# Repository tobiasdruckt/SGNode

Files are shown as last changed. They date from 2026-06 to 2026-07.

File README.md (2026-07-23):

# SGNode Intelligent Fermentation Assistant

**Release:** alpha 0.5.0  
**Platform:** ESP32 float + standalone ESP32 base station with 4-inch touchscreen

SGNode is a self-contained fermentation monitor and assistant. A battery-powered float measures tilt, temperature, and battery voltage. The base station receives data over ESP-NOW, stores batches on SD card, and provides all setup, charts, recommendations, and management directly on the built-in touchscreen.

No web UI, phone app, REST frontend, or external dashboard is used.

## Current Status

SGNode remains in **alpha** while SGNode Plug temperature control is still awaiting real water/fridge validation. Float/Base have completed real-batch use, but the Plug controller should pass water tests before the project moves to beta.

## Current Capabilities

### Base Station
- Native touchscreen UI with Live, Graph, Dashboard, Details, Battery, and More views
- Brew Wizard for batch name, style, volume, Brix, yeast, attenuation, and diacetyl rest
- Auto Mode with yeast behavior presets and custom yeast templates
- Brix to SG conversion, expected FG, attenuation, ABV, gravity slope, and ETA
- OG verification using first stable measured SG, with recipe/measured choice
- Batch-start float zero calibration with explicit "put float in brew" confirmation before logging
- Target gravity, temperature, angle, and ABV charts
- Fermentation state machine and on-device recommendations
- Batch management: continue, copy, and delete stored batches
- Yeast management: create, edit, delete, and select custom yeast presets
- Local persistence on SD card under `/data/batches/<batch_id>/`
- Debug levels for quieter serial output
- Light/dark theme with persistent setting
- Integration of SGNode Plug temperature control for precise fermentation temperatures
- Enhanced batch management: versioning and rollback options for stored batches
- Improved yeast management: compatibility with more yeast types and strain-specific parameters
- Real-time alerts for critical conditions such as excessive tilt or low battery voltage
- User feedback system for providing immediate suggestions based on sensor data and recipe adjustments

### Float Unit
- BMI160 tilt measurement and BMI160 chip-temperature diagnostics
- Polynomial gravity calibration stored in EEPROM
- ESP-NOW packet transmission with protocol version and CRC
- Battery voltage reporting
- Deep sleep between measurement cycles
- Calibration mode via hardware switch and base station workflow

## Hardware

### Float
- WeMos D32 ESP32 board with 18650 holder
- BMI160 IMU on I2C
- BMP180/GY-68 removed in the current low-power build
- 18650 Li-ion cell
- Calibration switch on GPIO12
- Waterproof enclosure

### Base
- 4.0-inch ESP32-32E touchscreen display module
- MicroSD card, FAT32
- 5V USB power supply
- Optional DS323x-compatible RTC on SDA GPIO32 and SCL GPIO25

See [hardware.md](hardware.md) and [WIRING_DIAGRAM.md](WIRING_DIAGRAM.md) for pin details.

## Firmware Layout

```text
SGNode_Base/
  SGNode_Base.ino                 Base station firmware and UI orchestration
  src/
    assets/                       Boot logo data
    calculations/                 Brix, gravity, ETA, OG, and target curve logic
    domain/                       Batch model, yeast presets, state, and recommendations
    test/                         Optional serial UI test harness
    ui/                           Brew Wizard and shared touchscreen UI helpers

SGNode_Float/
  SGNode_Float.ino                Float firmware
  polynomial_calibration.h         Float calibration logic

SGNode_Plug/
  SGNode_Plug.ino                 ESP8285 smart-plug temperature controller
  src/                            Plug sensors, ESP-NOW transport, PI control, and relay logic

SGNode_Shared/
  sg_protocol.h                   ESP-NOW payload format
  plug_hardware.h                 Plug pin assignment
```

## SD Card Structure

```text
/data/
  batches/
    batch_001/
      profile.json
      target.json
      log.csv
  yeast/
    <custom_yeast>.json
  yeasts.txt
  yeast_history.json
```

`log.csv` contains timestamp, epoch, uptime, angle, density, diagnostic float temperature, battery, fermentation state, attenuation, ABV, recommendation code, and optional Plug temperature-control fields. Historical data is loaded after reboot and should be visible immediately.

## Setup

1. Install Arduino IDE 2.x and ESP32 board support.
2. Install libraries:
   - TFT_eSPI
   - XPT2046_Touchscreen
   - EmotiBit BMI160
   - SD, FS, SPI, Wire, EEPROM
3. Configure TFT_eSPI for the 4.0-inch ESP32-32E display.
4. Flash `SGNode_Base/SGNode_Base.ino`.
5. Temporarily set `SGNODE_DEBUG_LEVEL` to `DEBUG_INFO` and read the base station MAC address from Serial Monitor.
6. Set that MAC in `SGNode_Float/SGNode_Float.ino`.
7. Flash the float.
8. Insert a FAT32 MicroSD card into the base station.
9. Use the touchscreen Brew Wizard to create the first batch.

Optional SGNode Plug build:

- Install ESP8266 board support.
- Install `OneWire` and `DallasTemperature`.
- Compile `SGNode_Plug/SGNode_Plug.ino` as `Generic ESP8266 Module`, 1 MB flash, DOUT flash mode, and 80 MHz CPU.
- Include the project root as a local library path so `SGNode_Shared` headers are visible.

## Normal Operation

1. Create or continue a batch on the base station.
2. Follow the Dashboard action `Level Float` if a batch-start zero calibration is required.
3. Place the float in the fermenter only after zero calibration is complete.
4. Confirm `Put Float In Brew` on the Dashboard.
5. The float wakes, measures, transmits, and returns to sleep.
6. The base station updates the Live screen, charts, dashboard, recommendations, ETA, and CSV log.
7. Use More > Manage Brew to continue, copy, or delete batches.
8. Use More > Manage Yeast to maintain custom yeast presets.

## Batch Start Workflow

SGNode intentionally separates preparation from the real batch start.

1. Brew Wizard creates the batch profile and target curve.
2. Dashboard shows `Level Float`.
3. Put the float on a level reference surface and press `READY`.
4. Base waits for the next normal float packet and sends a zero-calibration command in the ESP-NOW ACK.
5. Float performs a short accelerometer zero calibration, stores the offset, and reports success in a later packet.
6. Dashboard then shows `Put Float In Brew`.
7. Place the float in the wort/beer and press `DONE`.

Before `Put Float In Brew` is confirmed, incoming float packets are allowed to update the live display but are not written to the active batch CSV and are not used for OG detection or fermentation state changes. This prevents handling, air, and table measurements from contaminating the batch history.

When `Put Float In Brew` is confirmed:

- `createdAt` is reset to the confirmation time.
- the RAM write buffer is cleared.
- the active `log.csv` is recreated with only the header.
- the target curve is regenerated from the real batch start.
- OG stability detection and normal SD logging begin.

## Calibration

Calibration is started from the base station and executed by the float.

1. Turn on the float calibration switch.
2. Open More > Calibration on the base station.
3. Record the offset on a level surface.
4. Record SG points in known solutions.
5. Apply calibration to save polynomial coefficients to float EEPROM.
6. Turn off the calibration switch to return to deep sleep operation.

Current calibration uses the existing float firmware. Adding new optional calibration points normally requires float firmware changes because the float owns the polynomial calculation and EEPROM format.

### Batch-Start Zero Calibration

The batch-start zero calibration is separate from polynomial SG calibration. It only updates the accelerometer zero offset used for tilt.

- It runs in normal float operation, not in the long calibration mode.
- The float remains on a level reference surface.
- Base sends the zero-calibration command inside the normal ACK/downlink packet.
- Float uses a short sample window, saves the offset if the raw acceleration is plausible and stable, and then returns to sleep.
- If zero calibration fails, keep the float level and repeat the Dashboard action.

## Debug Output

Base station serial logging is controlled in `SGNode_Base.ino`:

```cpp
#define SGNODE_DEBUG_LEVEL DEBUG_ERROR
```

Levels:
- `DEBUG_QUIET`
- `DEBUG_ERROR`
- `DEBUG_INFO`
- `DEBUG_VERBOSE`

Use `DEBUG_INFO` temporarily for setup details such as the base station MAC address. Use `DEBUG_VERBOSE` only when diagnosing packet, SD, graph, or calibration behavior.

## Troubleshooting

### Historical graphs are empty after reboot
- Check Details > System:
  - `SD OK` means the active log path is usable.
  - `CSV L/T` means loaded rows / total rows.
  - `Buf` means unsaved RAM buffer entries.
- If `T` is correct but `L` is low, rows may be outside the selected time range or older than the active batch start timestamp.
- If `Buf` is high before reboot, those rows have not been flushed to SD yet.

### Old data appears in a new batch
- Confirm the active batch in Manage Brew.
- Current builds avoid reusing existing batch directories and filter rows older than the active batch creation time.
- For a new batch, confirm `Put Float In Brew` before expecting CSV rows. Data received before that confirmation is intentionally not logged.

### New batch receives float packets but log stays empty
- This is expected until `Put Float In Brew` has been confirmed.
- The Live screen can show current float data before the batch is armed.
- Confirm the Dashboard action after the float is actually in the wort/beer.

### No float data received
- Verify the base station MAC in the float sketch.
- Confirm both devices are powered.
- Check ESP-NOW channel and antenna placement.
- Use `DEBUG_INFO` or `DEBUG_VERBOSE` temporarily.

### SD card issues
- Use FAT32.
- Try a different MicroSD card.
- Insert the card before boot.
- Check that `/data/batches/<batch_id>/log.csv` exists.

### Battery drains too fast
- Verify the float is entering deep sleep.
- Keep calibration mode off during normal use.
- Confirm measurement delay/sleep interval settings.
- Current reference hardware reached about `0.95 mA` deep sleep after removing the BMP180/GY-68 and isolating the USB-UART chip.
- The ME6220 regulator swap did not provide enough improvement to justify the rework by itself.
- Check IMU suspend state and USB-UART leakage first if hardware current remains high.

## Release Notes

See [RELEASE_NOTES_v0.5.0-alpha.md](RELEASE_NOTES_v0.5.0-alpha.md).

## Status

alpha 0.5.0 is ready for hands-on testing. Float/Base have completed a first real batch, while SGNode Plug remains alpha until water/fridge validation is complete.

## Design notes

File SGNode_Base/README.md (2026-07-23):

# SGNode Base Firmware

## OTA Update

Base OTA is a manual maintenance mode.

1. Open the bottom `More` tab.
2. Tap `OTA Update`.
3. Confirm `Start Base OTA?`.
4. Connect to the SoftAP shown on the display, for example `SGNode-Base-OTA-xxxxxx`.
5. Open `http://192.168.4.1/` and upload the new `.bin`.

During OTA the base pauses normal ESP-NOW operation. The OTA mode stays active while a client is connected. If no client connects for 180 seconds, the base reboots back into normal operation.

The OTA page also provides compact diagnostics at `/diag` and a `Reboot normal mode` link.

## Display Brightness

The `More` tab has a `Brightness` item. It cycles through `Low`, `Mid`, `High`, and `Max` using PWM on GPIO27, which is the LCD backlight pin on the ESP32 display board.

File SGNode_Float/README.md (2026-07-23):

# SGNode Float Firmware

**Release:** alpha 0.5.0  
**Role:** Battery-powered ESP32 sensor float

The float measures tilt, diagnostic BMI160 chip temperature, and battery voltage, converts tilt to specific gravity using stored calibration coefficients, and sends packets to the base station via ESP-NOW.

## Hardware

- WeMos D32 ESP32 board with 18650 holder
- BMI160 IMU on I2C, GPIO26 SDA and GPIO27 SCL
- BMP180/GY-68 removed in the current low-power hardware revision
- Battery voltage divider on GPIO15
- Calibration switch on GPIO12
- Status LEDs on GPIO5 and GPIO16

## Main Behavior

1. Wake from sleep.
2. Read battery before Wi-Fi activity.
3. Initialize sensors.
4. Collect filtered tilt and temperature readings.
5. Calculate specific gravity.
6. Send ESP-NOW payload with protocol version and CRC.
7. Return to deep sleep.

Calibration switch ON keeps the float awake for the base station calibration workflow.

## OTA Update

Float OTA is a manual service mode.

1. Wake or power the float while holding the calibration switch.
2. Keep the switch held for 5 seconds.
3. The float sends an `OTA Active` packet to the base station, then starts a SoftAP such as `SGNode-Float-OTA-xxxxxx`.
4. Connect to the SoftAP and open `http://192.168.4.1/`.
5. Upload the new `.bin`.

During OTA the float does not enter deep sleep. The mode has a hard 20 minute timeout to protect the battery. Holding the calibration switch for 5 seconds while OTA is active reboots back to normal mode. The web page also has a `Reboot normal mode` link and compact diagnostics at `/diag`.

## Required Libraries

- EmotiBit BMI160
- Wire
- EEPROM

## Configuration

Set the base station MAC address in `SGNode_Float.ino`:

```cpp
uint8_t baseStationMac[] = {0xA4, 0xF0, 0x0F, 0x68, 0x22, 0x00};
```

The shared payload format is defined in `../SGNode_Shared/sg_protocol.h`.

## Calibration

Calibration coefficients are stored in EEPROM. The base station sends calibration commands while the float is in calibration mode.

Current behavior:
- Sensor offset calibration is supported.
- Multiple SG points are recorded.
- Polynomial coefficients are calculated on the float.
- EEPROM versioning is used for backward compatibility.

Adding extra optional calibration points normally requires flashing the float because the point handling, polynomial fit, and EEPROM format live in the float firmware.

## Power Notes

- Deep sleep is the expected normal state.
- Calibration mode has high drain because the float stays awake.
- Battery measurement uses GPIO15 with a calibrated voltage divider.
- If battery drain is high, first confirm that the float is not staying in calibration mode and that the sleep interval is actually reached after each send.

## Troubleshooting

- No packets: check base station MAC and ESP-NOW channel.
- Wrong SG: recalibrate and verify the float is mechanically stable.
- Unexpected temperature: remember this is BMI160 chip temperature for diagnostics, not beer temperature.
- Battery reads wrong: verify the divider and calibration factor.
- Fast drain: inspect deep sleep entry and sensor power behavior.

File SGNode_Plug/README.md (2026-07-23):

# SGNode Plug firmware

Target hardware: Gosund SP1 with ESP8285 and removed power-measurement circuit.

## Pin assignment

| GPIO | Function |
| --- | --- |
| 1 | Secondary LED |
| 3 | Button |
| 4 | Fridge-air DS18B20 data |
| 5 | Beer/vessel DS18B20 data |
| 13 | Primary LED |
| 14 | Relay, active high |

Each DS18B20 uses a separate OneWire bus and needs a 4.7 kOhm pull-up from
its data line to 3.3 V.

The relay is initialized OFF before any controller logic runs.

## Control behavior

- The Base sends beer target, ramp rate, and batch size by ESP-NOW.
- The Plug keeps a rolling beer-probe history and updates its outer controller
  once per minute.
- The outer PI/D-brake controller derives an air target. The inner controller
  switches the relay around that target with asymmetric thresholds above the
  air target. Current defaults switch off at air target + 0.5 K and on at air
  target + 1.1 K to compensate for fridge aftercool.
- If the beer probe fails while the air probe remains valid, the last air
  target is held.
- If the air probe fails, a complete learned six-hour compressor pattern is
  replayed. Without a complete pattern, the relay remains off.
- Every Plug status contains both temperatures, targets, controller state,
  faults, relay state, and the rolling ten-minute duty cycle.

Controller parameters are sent by Base with each command. Base stores the
editable defaults on the SD card in `/data/plug/gov_settings.json`.

The Base learns the MAC of the first valid Plug status packet and stores it in
EEPROM. Plug control remains disabled by default and can be enabled per batch
with the Brew Wizard `SGNode Plug` step.

## OTA update mode

Hold the Plug button for 5 seconds to enter OTA update mode. The relay is
switched off immediately and stays off. Normal ESP-NOW control is paused, and
the Plug starts an open SoftAP named `SGNode-Plug-OTA-<ChipId>`.

Connect to the AP and open:

- `http://192.168.4.1/`
- `http://192.168.4.1/update`
- `http://192.168.4.1/diag`

The root/update page contains a minimal firmware upload form, a normal-mode
reboot button, and compact diagnostics. After a successful upload the Plug
reboots. OTA mode remains active while a client is connected to the SoftAP. If
no upload is in progress and no client is connected for 180 seconds, OTA mode
times out and reboots so ESP-NOW starts cleanly again. Holding the hardware
button for 5 seconds while already in OTA mode also reboots to normal mode.

During OTA both LEDs blink. The secondary LED is on GPIO1/UART TX and may also
flicker when serial output is active.

## Build target

Use `Generic ESP8266 Module`, 1 MB flash, DOUT flash mode, and 80 MHz CPU.

Required libraries:

- OneWire
- DallasTemperature

The shared headers in `SGNode_Shared` are used as a local project library when
compiling the Plug.

## Bench-test order

The low-level bench-test sketches are intentionally local-only and ignored by
Git. Keep them beside the repo when working on hardware, but do not publish
them as part of the main firmware tree.

1. Flash local `SGNode_Plug_Hardware_Check` and verify the serial pin report.
2. With no 230 V connection, flash local `SGNode_Plug_Sensor_Relay_Test`.
3. Verify both temperatures on serial and relay continuity with a multimeter.
4. Flash `SGNode_Plug` only after the sensor assignment and relay polarity are
   confirmed.

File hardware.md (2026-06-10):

# SGNode Hardware Notes

**Current release:** alpha 0.5.0

## Bill Of Materials

### Float Unit

| Part | Qty | Notes |
| --- | ---: | --- |
| WeMos D32 ESP32 board | 1 | Built-in 18650 holder and charger |
| BMI160 IMU | 1 | Tilt measurement |
| BMP180 / GY-68 | 0 | Removed from current float build; BMI160 chip temperature is used for diagnostics |
| 18650 Li-ion cell | 1 | 2000 mAh or larger recommended |
| SPST switch | 1 | Calibration mode on GPIO12 |
| Waterproof enclosure | 1 | Must fit fermenter opening |

### Base Station

| Part | Qty | Notes |
| --- | ---: | --- |
| 4.0-inch ESP32-32E display module | 1 | Integrated ESP32, ST7796 display, touch |
| MicroSD card | 1 | FAT32, 4 GB or larger |
| 5V USB power supply | 1 | 2 A recommended |
| DS323x-compatible RTC | 1 | Optional but recommended for stable timestamps |

## Float Pin Summary

| Signal | GPIO | Notes |
| --- | ---: | --- |
| I2C SDA | 26 | BMI160 |
| I2C SCL | 27 | BMI160 |
| Battery ADC | 15 | 51k/51k divider plus capacitor |
| Calibration switch | 12 | Switch to GND |
| Built-in LED | 5 | Status |
| Extra LED | 16 | Calibration indicator |

## Float Hardware Revision Notes

- The BMP180/GY-68 has been removed from the float. It self-heated the small float interior and did not provide a reliable beer-temperature measurement.
- Current firmware reports BMI160 chip temperature. Treat this as a diagnostic value, not as representative wort/beer temperature.
- The current Float firmware no longer requires any BMP/BMP180 support library.
- The USB-UART chip was isolated by cutting pin 8 on the CP2302/USB-UART package used on the tested board. This reduced sleep leakage on the reference float.
- The voltage regulator was replaced with an ME6220 during testing. The improvement was small and is not considered worth the rework by itself.
- Current measured reference sleep current after the practical hardware changes is about `0.95 mA`.

## Base Pin Summary

The 4-inch base module has display, touch, and SD wiring integrated. Current firmware also supports an RTC:

| Signal | GPIO |
| --- | ---: |
| RTC SDA | 32 |
| RTC SCL | 25 |
| SD CS | 13 |
| Display CS | 5 |
| Touch CS | 15 |

## Assembly Notes

- Keep the float antenna area clear of metal.
- Mount the IMU rigidly; movement inside the enclosure will ruin calibration.
- Put the battery low in the float for stable orientation.
- Seal the float enclosure before real fermentation use.
- Keep SD card access available on the base enclosure.
- Use a stable 5V supply for the base station; display and SD writes need margin.

## Power Notes

### Float

- Normal operation should spend most time in deep sleep.
- Calibration mode keeps the float awake and drains the battery quickly.
- If drain is high, measure sleep current directly and confirm BMI160 suspend behavior and USB-UART leakage.
- Do not use the removed BMP180 as a beer-temperature reference in new builds.

### Base

- Designed for powered operation, not battery operation.
- Typical draw depends heavily on display backlight.
- SD access is mounted only when needed to reduce SPI/touch conflicts.

## Enclosure Targets

### Float

- PETG or ABS preferred.
- Waterproof target: IP67 style sealing.
- Stable buoyancy and consistent tilt response are more important than minimum size.

### Base

- Desktop stand or wall mount.
- Access for USB and MicroSD.
- Passive ventilation for ESP32 and display driver.

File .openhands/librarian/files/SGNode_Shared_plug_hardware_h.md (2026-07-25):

# SGNode_Shared/plug_hardware.h

**Type:** C++ Header
**Hash:** `9040c98aef18a2a87f8e2de6f7bfb239a11960e1cd32cc37a2c1f87b4a31860b`

## Overview / Role

Hardware pin definitions and inline functions

## Verified API & Symbols

### Functions

- `void beginRelayOff (void)`

- `void setRelay (bool on)`

## Key Dependencies

**System/External:**
- `<Arduino.h>`

## Side Effects & Hardware Access

- Relay control (fridge compressor)
- I2C bus communication
- OneWire bus communication
- Serial port initialization

## Change Risks

- **MEDIUM**: Core functionality change

---
*Last modified (hash): 9040c98aef18a2a87f8e2de6f7bfb239a11960e1cd32cc37a2c1f87b4a31860b*

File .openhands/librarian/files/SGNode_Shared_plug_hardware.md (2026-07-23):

# SGNode_Shared/plug_hardware.h

**Type:** C++ Header
**Hash:** `9040c98aef18a2a87f8e2de6f7bfb239a11960e1cd32cc37a2c1f87b4a31860b`

## Role

Hardware pin definitions and low-level control helpers.

## Verified API / Symbols

- Functions: beginRelayOff, setRelay

## Key Dependencies

- Arduino.h

## Side Effects

- Relay control (fridge compressor)
- I2C/SPI bus communication

## Tests

- No dedicated automated test identified

## Change Risks

- **MEDIUM**: Core functionality change

---
*Last modified (hash): 9040c98aef18a2a87f8e2de6f7bfb239a11960e1cd32cc37a2c1f87b4a31860b*

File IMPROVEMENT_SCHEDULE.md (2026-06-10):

# SGNode Improvement Backlog

**Updated:** 2026-06-10

**Current release:** alpha 0.5.0

This backlog tracks the active alpha work. Historical release contents live in the release notes; this file should stay focused on the next useful checks and implementation steps.

## Current Alpha Status

- Float/Base completed a first real fermentation run.
- SGNode Plug firmware and Base integration exist, but Plug control has not yet passed the water/fridge validation run.
- New batches are gated by quick zero calibration and a required `Put Float In Brew` confirmation before CSV logging starts.
- The current Float reference build removed the BMP180/GY-68. BMI160 chip temperature is kept as a diagnostic value only.
- Reference Float deep sleep current is about `0.95 mA` after practical low-power changes.
- Low-level Plug test sketches are kept local-only and ignored by Git.

## Completed Since v0.4.0

- Batch-start quick zero calibration via Float ACK command.
- Required `Put Float In Brew` action to separate setup packets from real batch logging.
- Manage Brew delete geometry and old-batch directory deletion fixes.
- SGNode Plug alpha firmware for Gosund SP1 / ESP8285.
- Base/Plug ESP-NOW command and status protocol.
- Base-side Plug MAC learning, persisted status, command sender, UI diagnostics, and CSV fields.
- Brew Wizard `SGNode Plug` step for per-batch Plug Auto Mode.
- Hardware documentation update for BMP removal, CP2302 pin isolation, and realistic regulator-swap benefit.

## Active Alpha Priorities

### 1. SGNode Plug Water/Fridge Validation

- Run the Plug with water, both DS18B20 sensors, and the fridge before using Plug Auto Mode on beer.
- Confirm relay polarity, command acknowledgement, stale-status handling, and compressor duty logging.
- Validate PI outer-loop behavior for realistic batch volumes and temperature ramps.
- Check cold-crash behavior with the 1.0 C absolute air-target clamp, static 3 K clamp, and dynamic 5 K clamp.
- Tune default `Tn` values after measured water-test response data exists.

### 2. Batch Start And Logging Validation

- Re-test the full new-batch flow on hardware: wizard, quick zero, `Put Float In Brew`, first logged CSV row.
- Confirm packets received before `Put Float In Brew` update the live display but do not enter the batch CSV.
- Confirm completed batches remain read-only enough for normal UI use.
- Keep active-batch restore behavior covered when older and newer batch directories coexist.

### 3. Fermentation Logic Validation

- Compare dry-hop, cold-hop, cold-crash, and package recommendations against real fermentation data.
- Validate action hysteresis so repeated recommendations do not appear and disappear around SG thresholds.
- Continue tuning ETA from smoothed recent SG slope and phase state.
- Store enough yeast performance summary data for future learning, but defer broad learning features until basic thresholds are stable.

### 4. Float Hardware And Power Validation

- Repeat sleep-current measurement after the BMP removal and calibration ACK changes.
- Confirm the BMI160-only build wakes, sends, receives calibration commands, and returns to deep sleep reliably.
- Document any remaining board-specific leakage paths only after measurement.
- Do not reintroduce BMP/BMP180 libraries or wiring for the current reference Float.

### 5. Documentation And Release Hygiene

- Keep README, hardware notes, wiring diagram, release notes, and Plug plan aligned before each GitHub push.
- Keep historical release notes historical; new behavior belongs in the current release notes.
- Keep local-only hardware test sketches out of Git while documenting their purpose.
- Revisit beta status only after Plug water/fridge validation is complete.

## Beta Gate

SGNode should stay alpha until these points are true:

- Plug water/fridge test passes without unsafe relay behavior.
- Plug and Base logs show coherent Float plus Plug rows over a realistic run.
- Batch-start gating is stable on real hardware.
- No critical SD/history loss is observed during normal reboot and batch-management flows.
- The documentation describes the actual hardware and required libraries without stale BMP or test-sketch assumptions.

## Later Ideas

- Sugar/priming calculator based on batch volume, target CO2, beer temperature, and bottle size.
- Centralized error code model.
- More robust settings screen.
- Export helpers for SD card data.
- Automated simulator tests for calculations and state machine.
- Optional additional calibration points if real Float data proves they are needed.

## Rule For Alpha

Prefer small, testable fixes over broad refactors. Every change should preserve existing manual mode, Auto Mode, SD history, batch-start gating, and calibration behavior.

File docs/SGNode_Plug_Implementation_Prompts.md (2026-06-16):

# SGNode Plug Implementation Prompts

Working notes for adding an ESP8285-based smart plug as a standalone fridge controller for SGNode.

These notes are intentionally split into small implementation prompts. Each prompt should be usable as a focused task later.

## Current Implementation Status

SGNode Plug is implemented and has passed initial bench plus first 13 L water/fridge validation, including clean 9 C and 4 C holds. It remains **alpha** until other fill levels and at least one real fermentation validate the controller.

| Stage | Status | Notes |
| --- | --- | --- |
| 1. Hardware validation | Done for current bench hardware | Gosund SP1, ESP8285, power metering removed, GPIO4/GPIO5 freed, relay active-high on GPIO14 |
| 2. Dual DS18B20 serial test | Done for current hardware | `SGNode_Plug_Sensor_Relay_Test` is kept local-only and ignored by Git; sensor assignment was validated before Plug firmware testing |
| 3. Plug firmware skeleton | Implemented | `SGNode_Plug/SGNode_Plug.ino` and supporting modules exist |
| 4. Local air controller | Implemented | Asymmetric air thresholds implemented; current defaults are off at air target + 0.5 K and on at air target + 1.1 K |
| 5. Rolling statistics and fallback | Implemented | 10-minute duty and six-hour pattern fallback implemented; replay behavior needs live validation |
| 6. ESP-NOW protocol | Implemented | Shared command/status structs, Base MAC learning, persisted Plug MAC, and status handling are present |
| 7. Outer PI beer controller | Implemented | Explicit Base-sent `Kp`, `Tn`, D-brake, clamps, and air-target derivation are implemented |
| 8. Base batch/UI integration | Implemented | Brew Wizard Plug toggle, Base command sender, status display, and Plug temperature preference are present |
| 9. Shared CSV integration | Implemented | Batch CSV includes Plug status fields while remaining backward-compatible |
| 10. Water tests and tuning | In progress | First 13 L test produced usable defaults; other fill levels and real fermentation validation remain before beta |

Open validation before beta:

- Validate both DS18B20 probes over longer operation on real wiring.
- Run low-voltage relay/contact test without 230 V load.
- Run water/fridge test with several fill levels.
- Validate PI `Kp`, batch-size-to-`Tn`, 3 K hold clamp, 5 K transition clamp, 1.0 C minimum air target, compressor timing, and fallback behavior.
- Confirm Base logs coherent Float + Plug rows during the test.
- Confirm cold-crash transition behavior with water before using Plug auto mode on a live batch.

## Implementation Order

Implement and validate SGNode Plug in the following order. Do not proceed to the next stage until the current stage has passed its checks.

### Stage 1: Hardware Validation

- Confirm GPIO4 and GPIO5 are electrically isolated after removing the power-metering hardware.
- Confirm GPIO14 relay is active-high.
- Confirm relay remains off during boot/reset/flash.
- Document final wiring and sensor cable routing.

Exit criteria:

- GPIO4/GPIO5 can be safely driven/read at 3.3 V.
- Relay behavior is known and repeatable.
- No mains-connected testing is required for unresolved low-voltage wiring.

### Stage 2: Dual DS18B20 Serial Test Sketch

- Create or keep a standalone local hardware-test sketch before implementing SGNode Plug firmware.
- Suggested local path: `SGNode_Plug_Sensor_Relay_Test/SGNode_Plug_Sensor_Relay_Test.ino`.
- Connect fridge-air DS18B20 to GPIO4.
- Connect vessel/beer DS18B20 to GPIO5.
- Use one 4.7 kOhm pull-up to 3.3 V on each data line.
- Read both sensors independently and print both temperatures over Serial.
- Print explicit errors for missing, disconnected, invalid, or CRC-failing sensors.
- Force GPIO14 low immediately at startup.
- After both sensors provide valid values, control the relay using a simple differential test rule:
  - If vessel/beer sensor is warmer than fridge-air sensor, switch cooling relay on.
  - If fridge-air sensor is warmer than vessel/beer sensor, switch cooling relay off.
- Add a small differential hysteresis to prevent relay chatter when both values are nearly equal.
- If either sensor is invalid, keep the relay off.
- Run this hardware test without 230 V AC connected.
- Verify relay contact continuity only with a multimeter.
- Do not connect a refrigerator or other mains load during this test.

Suggested Serial output:

```text
AIR 20.31 C | BEER 20.44 C | AIR_OK=1 | BEER_OK=1 | RELAY=ON | STATE=BEER_WARMER
```

Exit criteria:

- Both sensors are detected consistently across multiple resets.
- Both temperatures update independently.
- Disconnecting either sensor reports the correct individual fault.
- Relay switches on when the beer sensor is sufficiently warmer than the air sensor.
- Relay switches off when the air sensor is sufficiently warmer than the beer sensor.
- Relay does not chatter when both values are nearly equal.
- Invalid sensor data always switches or keeps the relay off.
- Multimeter continuity confirms the expected relay contact state.

### Stage 3: Plug Firmware Skeleton

- Create `SGNode_Plug/SGNode_Plug.ino`.
- Initialize relay safe-off, both sensors, timing, diagnostics, and fixed Base peer MAC.
- Implement controller state machine without switching a real compressor yet.
- Print calculated states and relay requests over Serial.

Exit criteria:

- Firmware boots reliably.
- Sensor readings and controller states are stable.
- No unexpected relay activation occurs.

### Stage 4: Local Air Two-Point Controller

- Implement the inner fridge-air controller.
- Add asymmetric thresholds relative to air target.
- Current defaults: relay off at air target + 0.5 K, relay on at air target + 1.1 K.
- Add minimum compressor off/on timing.
- Test first with a lamp or other non-compressor load if practical.

Exit criteria:

- Relay follows air target and hysteresis correctly.
- Minimum compressor timing cannot be bypassed.
- Relay remains off during invalid startup state.

### Stage 5: Rolling Statistics And Time-Pattern Fallback

- Add 10-minute temperature statistics and compressor duty.
- Add rolling six-hour relay-pattern recording.
- Add pattern replay on temperature-measurement failure.
- Keep relay off and report fault if no complete valid pattern exists.

Exit criteria:

- Statistics match measured intervals.
- Invalid sensor periods are not learned.
- Replay preserves the recorded duty pattern while respecting compressor timing.

### Stage 6: ESP-NOW Plug Protocol

- Add Plug command/status packet types to `SGNode_Shared`.
- Plug uses fixed Base MAC.
- Base learns first valid Plug MAC and stores it in EEPROM.
- Implement command acknowledgement, packet validation, status reporting, and `Forget SGNode Plug`.

Exit criteria:

- Plug and Base exchange validated packets reliably.
- Base restart restores learned Plug MAC.
- Foreign Plug packets are ignored after learning.

### Stage 7: Outer PI Beer-Temperature Controller

- Implement requested beer target, internal target ramp, PI controller, and anti-windup on Plug.
- Add batch-size-based `Tn`.
- Add 3 K holding clamp, dynamic 5 K transition clamp, and fast-ramp behavior.
- Report PI state and derived air target to Base.

Exit criteria:

- Controller behaves correctly in simulation/Serial diagnostics.
- Mode transitions are bumpless.
- Output clamps and 1.0 C minimum air target work as specified.

### Stage 8: Base Batch And UI Integration

- Add Plug Auto Mode selection and ramp settings to Batch Wizard.
- Add Plug status, temperatures, controller state, and faults to Base UI.
- Add automatic cold-crash start policy.
- Keep Dry Hop and Package manual.

Exit criteria:

- Existing batches load safely.
- Plug-disabled operation remains unchanged.
- Plug-enabled batch sends correct beer targets and ramps.

### Stage 9: Shared CSV Integration

- Extend the existing batch CSV with Plug values and 10-minute compressor duty.
- Keep parser backward-compatible.
- Use latest known Plug status for Float-triggered rows.

Exit criteria:

- Old CSV files still load.
- New rows contain coherent Float and Plug values.
- No separate Plug log is created.

### Stage 10: Water Tests And Tuning

- Run controlled water tests at multiple fill levels.
- Validate `Kp`, batch-size-to-`Tn` scaling, delays, clamps, and ramp behavior.
- Tune parameters before using automatic control on an active fermentation.

Exit criteria:

- Stable holding performance.
- Controlled ramp performance without excessive overshoot.
- Cold-crash behavior respects configured ramp and temperature limits.

## Current Preferred Concept

Build an SGNode Plug firmware for an ESP8285 smart plug with two added temperature sensors.

Architecture:

- SGNode Base owns fermentation logic, batch state, and the requested beer-temperature profile.
- SGNode Plug owns both temperature measurements and the complete temperature-control loop.
- Base sends only the requested beer temperature, control mode, and profile-transition information via ESP-NOW.
- Plug derives its own fridge-air target from measured beer temperature and controls the fridge relay locally.
- Plug reports both temperatures, derived air target, controller state, and relay state back to Base.
- Base and Plug communication continues independently from Float packets.
- Float packets remain the primary trigger for combined batch CSV rows, but not for temperature-control availability.

Initial control strategy:

- Plug measures fridge air temperature with one DS18B20.
- Plug measures vessel/beer temperature through an immersion sleeve with a second DS18B20.
- When Plug Auto Mode is selected, Plug uses the immersion-sleeve temperature as its controlled process value.
- Float temperature remains available for diagnostics and logging, but is ignored by temperature control while Plug Auto Mode is active.
- Base sends the requested beer-temperature target from the active batch profile.
- Plug runs a slow outer beer-temperature controller that derives a fridge-air target.
- Plug runs an inner two-point fridge-air controller around that derived air target.
- Inner-loop thresholds: cooling on at air target + `Air on`, cooling off at air target + `Air off`.
- Current defaults are `Air off = 0.5 K` and `Air on = 1.1 K` to account for fridge aftercool.
- Plug sends average actual air temperature to Base every 10 minutes.
- Plug adapts its air-temperature target slowly based on the difference between immersion-probe temperature and requested beer target.
- Adaptive correction must be conservative, bounded, autonomous, and visible on Base through status reporting.

Action policy:

- Dry hop requires manual acknowledgement because SGNode cannot know whether hops were physically added.
- Remove dry hop requires manual acknowledgement or skip because SGNode cannot know whether hops were physically removed.
- Cold crash may auto-start when plug auto mode is enabled, the plug is reachable, all previous manual actions are resolved, and SGNode successfully commands the cold-crash target.
- Packaging remains manual.

## Prompt 1: Hardware Discovery

Inspect the ESP8285 smart plug hardware and document the pinout.

Known hardware:

- Smart plug: Gosund SP1
- MCU: ESP8285
- Jumper wires have already been soldered and routed outside the enclosure.

Confirmed external wiring:

| Wire color | Signal |
| --- | --- |
| Purple | RST |
| Blue | GPIO0 |
| Red | 3.3 V |
| Black | GND |
| White | ESP RX |
| Brown | ESP TX |
| Green | GPIO4, freed by removing the power-metering hardware |
| Yellow | GPIO5, freed by removing the power-metering hardware |

Planned sensor assignment:

| GPIO | Sensor role |
| --- | --- |
| GPIO4 | DS18B20 fridge-air sensor |
| GPIO5 | DS18B20 vessel/beer immersion-sleeve sensor |

GPIO4 and GPIO5 are intended as separate OneWire buses. Each bus receives its own pull-up resistor to 3.3 V.

Confirmed hardware modification:

- The power-metering hardware connected to GPIO4/GPIO5/GPIO12 has been desoldered.
- GPIO4 and GPIO5 are therefore available for the two DS18B20 buses.
- Plug power-consumption measurement is intentionally no longer available.
- Before connecting sensors, verify that GPIO4 and GPIO5 are electrically isolated from the removed metering circuit and switch cleanly between 0 V and 3.3 V.

Confirmed control pin behavior:

- Relay: GPIO14, active-high.
- Relay off: GPIO14 low.
- Relay on: GPIO14 high.
- Firmware must configure GPIO14 low as early as possible during boot.

Goals:

- Confirm the exact ESP8285 module/board revision used by this Gosund SP1.
- Use the confirmed Gosund SP1 assignment: GPIO14 relay, GPIO3 button, GPIO1/GPIO13 inverted LEDs.
- Identify safe flash pins and serial pads.
- Document mains-safety notes.
- Decide where an external temperature sensor can be physically routed.

Output:

- Add or update a hardware note for the plug.
- Include a pinout table.
- Include any unknowns that still need measurement.

## Prompt 2: Sensor Choice And Wiring

Wire and validate the two Plug temperature sensors.

Current decision:

- Use two DS18B20 temperature sensors.
- One sensor measures air temperature inside the fridge.
- One sensor measures vessel/beer temperature through an immersion sleeve.
- GPIO4 and GPIO5 are available, so each sensor uses its own OneWire bus.
- The original power-metering hardware has been removed to free GPIO4 and GPIO5.
- Sensors have been ordered.

Questions to resolve:

- Confirm a 4.7 kOhm pull-up from each sensor data line to 3.3 V.
- How to route sensor wiring without compromising electrical safety or enclosure integrity?

Sensor placement decision:

- Place the fridge-air sensor freely in the middle region of the refrigerator air volume.
- Keep it away from refrigerator walls, evaporator surfaces, direct cold-air outlets, and the fermentation vessel.
- Protect it from condensation and dripping water without thermally insulating it from the surrounding air.
- Fix its position so measurements remain comparable between batches.
- Insert the vessel/beer sensor fully to the end of the immersion sleeve.
- Use a small amount of food-safe thermal compound if needed for repeatable thermal contact.
- Secure and strain-relieve both sensor cables.
- Mark both cables clearly as `AIR` and `BEER`.
- Route sensor cables separately from mains-voltage and relay wiring wherever practical.

Placement validation:

- Verify that the air sensor responds substantially faster than the immersion-sleeve sensor during compressor cycling.
- Verify that the immersion-sleeve reading is stable and representative of vessel temperature.
- Record the installed positions so water tests and later batches remain comparable.

Output:

- Recommended sensor.
- Wiring table for both sensors.
- Pull-up requirements.
- Safety constraints.
- Sensor-role validation so swapped or faulty sensors can be detected.

## Prompt 3: ESP-NOW Protocol

Define the SGNode Base <-> SGNode Plug ESP-NOW protocol.

Base to Plug command fields:

- protocol version
- plug id
- requested beer target temperature C
- control mode: off, cooling, disabled/failsafe
- desired beer-temperature ramp rate or transition mode
- command sequence number
- timestamp or monotonic age reference

Plug to Base status fields:

- protocol version
- plug id
- current air temperature C
- current vessel/beer temperature C
- 10-minute average air temperature C
- 10-minute average vessel/beer temperature C
- minimum and maximum air temperature in report window
- minimum and maximum vessel/beer temperature in report window
- relay state
- compressor on-time ratio for the latest 10-minute report interval
- controller state
- derived fridge-air target
- active adaptive offset
- measured beer-temperature rate
- last command age
- uptime
- fault flags
- sequence acknowledgement

Sensor fault flags must distinguish:

- fridge-air sensor fault
- vessel/beer sensor fault
- implausible sensor-role swap or temperature relationship

Output:

- Add protocol structs to `SGNode_Shared`.
- Keep packet size small and fixed.
- Include versioning and sanity checks.

## Prompt 4: Plug Firmware Skeleton

Create a new Arduino sketch for the ESP8285 plug.

Suggested folder:

- `SGNode_Plug/SGNode_Plug.ino`

Core behavior:

- Boot with relay off.
- Initialize both DS18B20 sensors on separate OneWire buses.
- Initialize ESP-NOW.
- Register the known Base MAC as the Plug's fixed ESP-NOW peer.
- Accept control commands only from the configured Base MAC.
- Receive Base command packets.
- Run complete local cascaded temperature controller.
- Derive fridge-air target from requested beer target and immersion-probe feedback.
- Run local two-point air-temperature controller.
- Enforce compressor protection.
- Send status packets every 10 minutes.
- Send faster debug/status packets during startup if useful.

Safety behavior:

- Relay off until a valid command is received.
- Plug continues local control between Base updates.
- Plug stores the last valid derived fridge-air target.
- As long as fridge-air temperature remains plausible, Plug continues local air-temperature control using the last valid derived air target.
- Plug continuously records the compressor relay pattern for the last six hours while temperature measurements are valid.
- If temperature measurement is unavailable or implausible, Plug enters time-pattern fallback and repeats the last valid six-hour compressor pattern.
- Compressor minimum on/off protection remains active while replaying the pattern.

Output:

- Compileable ESP8285 firmware.
- No dependency on Wi-Fi router, MQTT, or web UI.

## Prompt 5: Local Plug Controller

Implement the local two-point fridge controller in the plug firmware.

Initial algorithm:

- Cooling on if `airTemp >= airTarget + Air on`.
- Cooling off if `airTemp <= airTarget + Air off`.
- Default thresholds: `Air off = 0.5 K`, `Air on = 1.1 K`.
- Enforce minimum compressor off time, default 5 minutes.
- Optional minimum on time, default 2 minutes.
- Relay must remain off when mode is disabled or sensor is invalid.

Control sensor roles:

- Local two-point relay control uses fridge-air temperature.
- Plug outer-loop/adaptive control uses vessel/beer temperature.
- Base provides only the requested beer-temperature target and phase/transition intent.
- A failed fridge-air sensor prevents safe local relay control.
- A failed vessel/beer sensor pauses the outer beer-temperature controller.
- When the vessel/beer sensor fails, Plug continues the inner air-temperature controller using the last valid derived air target, as long as fridge-air temperature remains plausible.
- Sensor failures and degraded air-only control are reported to Base.
- If fridge-air temperature also fails or becomes implausible, Plug stops temperature-based control and enters six-hour time-pattern fallback.

Time-pattern fallback:

- Maintain a rolling six-hour history of relay on/off state.
- Record history only while the required temperature measurements are valid and normal control is active.
- On temperature-measurement failure, repeat the most recent valid six-hour relay pattern.
- Continue enforcing minimum compressor off time and minimum compressor on time.
- Do not modify the adaptive air target while replaying the pattern.
- Report fallback state, pattern age, and replay position to Base.
- If no complete valid six-hour history exists, keep the compressor relay off and report the fault to Base.

Output:

- Controller function with unit-testable logic if practical.
- Clear state names for UI/status reporting.

Suggested controller states:

- `BOOT_SAFE_OFF`
- `WAITING_FOR_COMMAND`
- `IDLE_IN_BAND`
- `COOLING_ON`
- `MIN_OFF_TIME_LOCKOUT`
- `MIN_ON_TIME_HOLD`
- `SENSOR_FAULT`
- `AIR_ONLY_HOLD`
- `TIME_PATTERN_FALLBACK`

State outputs:

- Relay state.
- Reason why relay is on/off.
- Last valid command age.
- Sensor validity.
- Whether the controller is holding the last valid air target.
- Whether the controller is replaying a compressor pattern.
- Age of the recorded pattern and current replay position.

## Prompt 6: Base Integration

Integrate SGNode Plug support into SGNode Base.

Base responsibilities:

- Learn the Plug MAC from the first valid Plug status packet and persist it in EEPROM.
- Send requested beer temperature from the active batch profile via ESP-NOW.
- Send transition/ramp intent when the profile target changes.
- Show plug status on the display.
- Show fridge air temperature average.
- Show vessel/beer temperature from the Plug.
- Show derived fridge-air target and adaptive offset calculated by Plug.
- Show relay/cooling state.
- Show stale/failsafe warning if plug status is old.
- Auto-start cold crash when all guardrails are satisfied.

Output:

- Base compiles for ESP32 huge app partition.
- Plug control can be enabled/disabled from UI or config.
- Existing float communication remains unaffected.

## Prompt 6B: Batch Wizard Plug Setup

Extend batch creation to ask whether SGNode Plug temperature control should be used.

Wizard behavior:

- If a paired plug is available, offer Plug Auto Mode during batch creation.
- If a paired plug is reachable, default to Auto Mode but still show the choice.
- If no plug is reachable, show that the temperature profile will be advisory only.
- Store the chosen mode in the batch profile or associated batch settings.
- When Plug Auto Mode is enabled, identify Plug vessel/beer temperature as the authoritative temperature for Base display, logging, and batch analysis. Plug still performs the control loop locally.
- When Plug Auto Mode is enabled, allow selection of normal temperature-change and cold-crash ramp rates.
- Ramp-rate inputs must be constrained to sensible ranges.

Suggested UI text:

- `SGNode Plug found`
- `Use Plug Auto Mode?`
- `Temperature profile will control fridge`
- `Beer temperature source: Plug probe`
- `Normal ramp`
- `Cold crash ramp`
- `No plug found - profile display only`

Output:

- Batch stores whether plug control is enabled.
- Batch stores selected plug id/MAC if needed.
- Existing batches without plug settings load safely with plug control disabled.
- Batch profile stores the selected normal and cold-crash ramp rates.

Initial ramp-rate proposal for later validation:

| Ramp type | Default | Initial selectable clamp |
| --- | --- | --- |
| Normal fermentation temperature change | 0.2 K/h | 0.1-0.5 K/h |
| Cold crash | 1.0 K/h | 0.5-1.5 K/h |

Notes:

- The current observed cold-crash response was approximately 1.2 K/h at about 10 K air-to-vessel difference.
- Defaults and clamps should remain easy to revise after more real batch data is available.
- Plug receives the selected ramp rate with each relevant Base command and performs the ramp locally.

## Prompt 6C: Float-Ticked Plug Exchange

Use incoming Float packets as the main timing source for combined analysis and CSV logging, but keep Plug control communication independent.

Float-triggered cycle:

1. Base receives Float packet.
2. Base updates SG, Float diagnostics, fermentation state, and batch action state.
3. Base requests or reads latest Plug status.
4. Base computes the requested beer target from the batch temperature profile.
5. Base sends requested beer target and transition intent to Plug.
6. Plug independently computes its air target and relay state.
7. Base logs Float and latest Plug data in the same batch CSV row.

Notes:

- Plug must continue local control even if Float packets are delayed.
- Base sends Plug commands and heartbeats independently from Float packets, initially about every 1-2 minutes.
- Plug answers Base commands with current status.
- Plug additionally maintains and reports its 10-minute statistics.
- Base uses the latest known Plug status when writing the next Float-triggered CSV row.
- Plug status should include command sequence acknowledgement so Base can tell whether the latest target was accepted.

Output:

- Clear update order in Base.
- No direct dependency on Wi-Fi, MQTT, or router infrastructure.

## Prompt 6D: Shared CSV Logging

Add Plug values to the active batch CSV.

Preferred approach:

- Keep one CSV row per Float measurement.
- Add Plug-related columns to the existing row.
- Leave fields empty or zero/default when Plug is disabled or stale.
- Use only the active batch CSV; do not create a separate high-resolution Plug log.
- Store the compressor on-time ratio for the approximately 10-minute interval between data points instead of logging every relay transition.

Candidate new columns:

- `beer_target_temp`
- `beer_temp_source`
- `plug_beer_temp`
- `plug_beer_avg_10m`
- `plug_beer_min_10m`
- `plug_beer_max_10m`
- `float_temp`
- `fridge_air_target`
- `fridge_air_temp`
- `fridge_air_avg_10m`
- `fridge_air_min_10m`
- `fridge_air_max_10m`
- `fridge_relay_state`
- `fridge_compressor_duty_10m`
- `fridge_controller_state`
- `plug_last_seen_s`
- `plug_fault_flags`
- `plug_command_seq`
- `plug_ack_seq`

Questions:

- Whether to rename existing temperature columns for clarity.
- How to preserve compatibility with existing CSV readers.

Output:

- Updated CSV header.
- Updated CSV append code.
- Parser remains backward compatible with old CSV files.
- Compressor duty value is represented consistently, preferably as percent from 0-100.

## Prompt 7: Plug Cascaded Temperature Controller

Plan and implement the autonomous cascaded temperature controller on SGNode Plug.

Idea:

- Base sends the requested beer-temperature target.
- Plug compares immersion-sleeve beer temperature to the requested beer target.
- Plug uses a PI controller to calculate its internal fridge-air target offset.
- Plug uses fridge-air temperature and two-point hysteresis to control the relay.
- Adjustment must be slow because beer temperature is thermally lagged.

Possible guardrails:

- Update offset no faster than every 30-60 minutes.
- Use a dynamic offset clamp based on operating phase, desired beer-temperature ramp, and observed beer-temperature response.
- Ignore offset updates during active compressor transitions.
- Ignore offset updates if float data is stale.
- Prefer stable trend windows over single readings.

Output:

- Written algorithm proposal.
- Plug runtime flag to enable/disable adaptive outer-loop mode.
- Plug status reports requested beer target, measured beer temperature, derived air target, and adaptive offset.
- Base UI displays those reported values.

Outer PI controller concept:

- Controlled value: vessel/beer temperature from the immersion-sleeve DS18B20.
- Setpoint: requested beer temperature sent by Base.
- Controller output: fridge-air target offset relative to requested beer temperature.
- `beerError = plugBeerTemp - requestedBeerTarget`.
- Positive beer error requests a colder fridge-air target.
- Negative beer error requests a warmer fridge-air target or compressor inactivity.
- Current implementation: Base sends the active controller parameters with each Plug command.
- `Tn` is currently an explicit editable value from `/data/plug/gov_settings.json`.
- Batch-size-dependent `Tn` scaling remains a future refinement after more fill-level tests.
- Apply anti-windup whenever the controller output reaches its active offset clamp.
- Freeze or back-calculate the integral term while compressor operation cannot affect the requested direction.
- Filter beer temperature and rate before feeding the PI controller.
- Do not update the controller from single noisy readings.

PI output clamps:

- Holding mode: maximum air-to-beer target offset magnitude of 3 K.
- Controlled ramps up to and including 0.8 K/h: dynamic output clamp up to 5 K.
- Cooling ramps above 0.8 K/h: fast-ramp behavior with minimum fridge-air target of 1.0 C.

Deferred `Tn` scaling concept:

- Larger batches receive a longer `Tn`.
- Smaller batches receive a shorter `Tn`.
- Clamp `Tn` to a sensible minimum and maximum so invalid batch sizes cannot create unstable behavior.
- The exact batch-size-to-`Tn` relationship must be validated experimentally.
- Keep the relationship configurable rather than scattering constants through control logic.

Current tested controller defaults:

```text
Kp = 0.45
Tn = 0.75 h
D brake = 0.80 h
Air off = +0.50 K above air target
Air on = +1.10 K above air target
Beer undershoot lockout = 0.10 K
D max = 0.90 K
Warming D factor = 0.25
```

Future example `Tn` values if batch-size scaling is introduced:

| Batch size | Initial Tn |
| ---: | ---: |
| 5 L | 3.0 h, minimum clamp |
| 10 L | 4.6 h |
| 13 L | 6.0 h |
| 20 L | 9.2 h |
| 25 L | 11.5 h |
| 30 L | 12.0 h, maximum clamp |

Current reasoning:

- The first clean 13 L water/fridge validation showed the 9 C hold stable enough with these values.
- The fridge has noticeable aftercool after relay-off, so `Air off` and `Air on` are intentionally above the computed air target.
- The 4 C hold looked clean on the earlier SD data; additional fill levels and real fermentation heat are still needed before treating these as universal defaults.

Initial controller execution rules:

- Run the outer PI calculation once per minute.
- Use a filtered immersion-probe temperature. Current control uses the most recent short control average and a longer history for rate estimation.
- Use an error deadband of approximately +/- 0.1 K in holding mode.
- Ramp the beer setpoint internally rather than stepping directly to the final target.
- Apply conditional-integration anti-windup: do not integrate further when the output is clamped and the current error would drive it farther into saturation.
- Allow the integral term to unwind when the error direction moves the output away from saturation.
- Reset or safely initialize the integral term when starting a new batch or changing controller mode.
- Prefer bumpless transfer when switching between holding, controlled-ramp, fast-ramp, and air-only-hold modes.

Water-test plan for tuning:

- Test several fill levels, including approximately 5 L, 13 L, and the largest expected batch.
- At each fill level, measure response to known fixed air-to-water offsets such as 2 K, 3 K, and 5 K.
- Record delay before water temperature responds, stable cooling/heating rate, overshoot, compressor duty, and recovery after target arrival.
- Start with P-only tests where practical before enabling the integral term.
- Tune `Kp` first, then validate the batch-size-to-`Tn` relationship.
- Keep the initial linear `Tn` scaling unless test data clearly supports a different relationship.
- Do not tune using active fermentation as the first test because fermentation heat adds an uncontrolled disturbance.

Observed system response:

- During a manually started cold crash, approximately 10 K difference between fridge air and vessel/float temperature produced about 1.2 K per hour beer-temperature decrease.
- Treat this as an initial real-world data point, not yet as a fixed model constant.

Dynamic clamp concept:

- In steady holding mode, clamp the air-to-beer target offset to a maximum magnitude of 3 K.
- During a controlled cooling transition at or below 0.8 K/h, dynamically vary the permitted air-to-beer offset up to a maximum magnitude of 5 K.
- The dynamic offset should grow only as needed to achieve the requested beer-temperature ramp and shrink as the measured ramp approaches or exceeds the request.
- Reduce the permitted offset as the beer temperature approaches its target.
- Use measured float-temperature slope as feedback.
- Prevent the adaptive controller from continuing a large offset after the requested ramp has been reached.
- Keep absolute air-temperature safety limits separate from the dynamic offset clamp.

Fast cooling ramp decision:

- For commanded cooling ramps above 0.8 K/h, allow aggressive cooling without the normal dynamic air-to-beer offset clamp.
- During this fast-ramp mode, clamp the derived fridge-air target to a minimum of 1.0 C unless later tests justify a colder target.
- The normal asymmetric air thresholds remain active around that target.
- With a 1.0 C minimum air target and the current `Air off = 0.5 K`, measured fridge-air temperature should normally switch the compressor off around 1.5 C before aftercool.
- There is no separate 1.0 C measured-air hard shutdown in this mode.
- The refrigerator itself has an independent hard limiter at 0 C, providing the final physical low-temperature protection.
- SGNode Plug must not rely on the refrigerator limiter for normal regulation; it remains a last protection layer.
- Exit fast-ramp mode and restore normal dynamic clamping when the requested cooling ramp is 0.8 K/h or lower, or when the vessel temperature approaches its target.
- This rule applies to cooling ramps only; warming ramps do not request compressor cooling.

Candidate transition relationship for later validation:

```text
observed 10 K air/beer offset -> approximately 1.2 K/h beer cooling
initial estimated gain -> approximately 0.12 (K/h) per K offset
```

This relationship should be learned or validated over multiple transitions before it controls the full allowed offset.

Adaptive update guardrails:

- Both local Plug sensors are valid and fresh.
- Plug Auto Mode command from Base is valid and fresh enough.
- Compressor has not just switched state.
- System is not in sensor fault.
- During cold crash and other transitions, switch from steady-state offset control to ramp-aware dynamic clamp control.

State to expose:

- `beerTargetTempC`
- `beerActualTempC`
- `beerTempSource`
- `floatTempDiagnosticC`
- `fridgeAirTempC`
- `airTargetBaseC`
- `adaptiveOffsetC`
- `airTargetCommandedC`
- `adaptiveEnabled`
- `adaptiveLimited`
- `piKp`
- `piTn`
- `piIntegral`
- reason when adaptation is paused

## Prompt 7A: Temperature Control State Model

Define the temperature-control state shared between Base UI, Base logs, and Plug status.

Base-side states:

- `TEMP_CONTROL_OFF`
- `TEMP_PROFILE_ADVISORY`
- `TEMP_AUTO_WAITING_FOR_PLUG`
- `TEMP_AUTO_ACTIVE`
- `TEMP_AUTO_STALE`
- `TEMP_AUTO_FAULT`
- `TEMP_AUTO_COLD_CRASH`

Plug-side states:

- `PLUG_OFF`
- `PLUG_WAITING_FOR_COMMAND`
- `PLUG_IDLE_IN_BAND`
- `PLUG_COOLING`
- `PLUG_LOCKOUT_MIN_OFF`
- `PLUG_HOLD_MIN_ON`
- `PLUG_SENSOR_FAULT`
- `PLUG_AIR_ONLY_HOLD`
- `PLUG_TIME_PATTERN_FALLBACK`

Important distinctions:

- Base decides fermentation and target profile state.
- Base sends the requested beer-temperature target but does not calculate the air target.
- Plug decides derived air target, adaptive offset, and immediate relay state.
- Plug immersion probe is the process measurement used by the Plug controller.
- Float temperature remains logged as a secondary diagnostic measurement.
- Cold crash auto-start is a Base action that sends a lower target to Plug.
- Plug never decides batch actions such as dry hop, cold crash, or package.

Output:

- State enum definitions.
- Mapping to display labels.
- Mapping to CSV fields.
- Fault/stale behavior rules.

## Prompt 8: Testing Plan

Create a test plan for the plug and Base integration.

Tests:

- Relay starts off after boot.
- Relay remains off without valid command.
- Relay turns on above upper threshold.
- Relay turns off below lower threshold.
- Compressor minimum off time is respected.
- Sensor failure forces relay off.
- Fridge-air sensor and vessel/beer sensor faults are reported separately.
- Failed vessel/beer sensor pauses adaptive control but continues air control at the last valid air target.
- Failed or implausible fridge-air temperature enters six-hour time-pattern fallback.
- Time-pattern fallback repeats the last valid relay pattern.
- Time-pattern fallback still respects compressor minimum on/off times.
- Invalid sensor periods are not learned into the fallback pattern.
- Temperature failure without a complete valid six-hour pattern keeps the relay off and reports a fault to Base.
- Cooling ramps above 0.8 K/h enter fast-ramp mode without the normal dynamic offset clamp.
- Fast-ramp mode never commands a fridge-air target below 1.0 C.
- With the current asymmetric thresholds, fast-ramp mode still turns the compressor off above the air target to compensate for aftercool.
- Refrigerator hard limiter at 0 C remains independent and is not part of the normal Plug control algorithm.
- Holding mode clamps air-to-beer target offset to 3 K.
- Controlled cooling ramps at or below 0.8 K/h dynamically clamp air-to-beer target offset to at most 5 K.
- Larger batch sizes select a longer PI integral time than smaller batch sizes.
- Invalid batch sizes cannot select a `Tn` outside configured limits.
- PI integral anti-windup works at the 3 K, 5 K, and fast-ramp output limits.
- Current controller defaults are `Kp = 0.45`, `Tn = 0.75 h`, and `D brake = 0.80 h`.
- Batch-size-based `Tn` scaling is deferred until more fill-level data supports it.
- Controller uses filtered beer temperature and holding deadband.
- Mode changes do not create a sudden unsafe air-target jump.
- Plug Auto Mode selects immersion-probe temperature as authoritative for Base display, logging, and batch analysis.
- Disabling Plug Auto Mode restores Float temperature as the Base-side beer-temperature source.
- Float temperature remains logged while ignored by temperature control.
- Status packet reports average/min/max over 10 minutes.
- Status packet and shared CSV report compressor duty ratio for the latest 10-minute interval.
- Base displays stale plug warning.
- Existing Float ESP-NOW packets still work.

## Prompt 6A: Action Automation Policy

Define which batch actions can be automatically acknowledged by SGNode when Plug auto mode is enabled.

Policy:

- `Dry Hop`: manual only.
- `Remove Dry Hop`: manual or skip only.
- `Cold Crash`: auto-start allowed.
- `Package`: manual only.

Cold crash auto-start guardrails:

- Plug auto mode is enabled for the batch.
- Plug status is fresh.
- Plug has accepted the latest command or status confirms the requested mode.
- Dry hop is either disabled, skipped, or done and removed/skipped.
- Fermentation state indicates final gravity stable or ready for cold crash.
- Cold crash has not already been done or skipped.

Cold crash auto-start behavior:

- Set `coldCrashDone` or equivalent started state according to the existing profile model.
- Set `coldCrashStartedAt`.
- Append an event such as `COLD_CRASH_AUTO_STARTED`.
- Send the cold-crash air-temperature target to the plug.
- Display that cold crash was auto-started by SGNode.

Open design note:

- The current profile model uses `coldCrashDone` as the action acknowledgement flag. Decide whether this should mean "cold crash started" or whether a separate `coldCrashStarted` state is needed before implementation.

Output:

- Manual test checklist.
- Serial diagnostics commands if needed.
- Arduino compile commands for Base and Plug.

## Pairing Decision

- The SGNode Base MAC address is known before flashing SGNode Plug.
- The Base MAC is compiled or configured into Plug firmware.
- Plug registers this fixed Base MAC as its ESP-NOW peer.
- Plug accepts commands only from the configured Base MAC.
- No button-based Plug pairing workflow is required for the first version.
- Base learns the sender MAC from the first valid Plug status packet.
- Base stores the learned Plug MAC in EEPROM and restores it after reboot.
- After a Plug MAC has been learned, Base accepts Plug status only from that MAC.
- Base must validate packet type, protocol version, size, and checksum before learning the sender MAC.
- Base provides a confirmed menu action named `Forget SGNode Plug`.
- After confirmation, Base deletes the persisted Plug MAC from EEPROM.
- The next valid Plug status packet is learned automatically as the new Plug.
- While a Plug MAC is stored, valid-looking status packets from other MAC addresses are ignored.
- Forget/relearn actions should be written to diagnostics or event output.

## Open Questions

- Verify GPIO4/GPIO5 electrical isolation after removing the power-metering hardware.
- Validate the current controller defaults on other fill levels and a real fermentation.
- Decide whether explicit `Tn` remains a global editable setting or becomes batch-size-derived with an editable multiplier.

## Deferred Topics

- Float-temperature fallback when the immersion probe fails or is displaced.
- Immersion-probe displacement detection.

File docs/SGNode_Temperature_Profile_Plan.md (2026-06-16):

# SGNode Temperature Profiles For Yeast And Beer Styles

## Summary

- Temperature guidance is built as a profile-family system for all existing yeast presets, not as a W-34/70/Pils-only special case.
- Primary derivation: yeast and `curveTemplate` first; beer style only acts as a light modifier.
- Biological temperature intent and Plug control tuning stay separate:
  - Base owns the beer target profile and phase/action state.
  - Plug owns local fridge control and turns the requested beer target into an air target.
- Profile data is stored in `profile.json`. Existing batches without `temperatureProfile` remain legacy and continue using the current min/max midpoint logic.
- The wizard stays compact: SGNode generates an automatic profile, shows a summary, and keeps Advanced editing to core values.
- First Plug controller defaults now come from the 13 L water/fridge validation run, including clean 9 C and 4 C holds. Yeast/style temperature-profile defaults still need to be derived separately from fermentation intent and later real-batch data.
- After manual package confirmation, SGNode can continue supporting bottle conditioning and storage with Plug air-only temperature control.

## Profile Families

Supported v1 families:

| Family | Presets / Use |
| --- | --- |
| `clean_ale` | US-05, Nottingham, Generic Ale |
| `fast_ale` | S-04 |
| `slow_clean_ale` | K-97 / Koelsch / German Ale |
| `lager` | W-34/70, S-23, Generic Lager |
| `very_fast_ale` | Voss Kveik |
| `high_attenuation_saison` | Belle Saison |

Custom yeasts derive their profile from `curveTemplate`, recommended min/max temperature, fermentation speed, and diacetyl-rest flag.

Main target selection:

- `lager`: lower yeast range. W-34/70 default: pitch 9 C, main 10 C, D-rest 15 C, crash 4 C, lagering hint 2 C.
- `clean_ale`: middle to slightly lower yeast range.
- `fast_ale`: middle yeast range with shorter hold times.
- `slow_clean_ale`: cool, clean ale range; D-rest when the preset recommends it.
- `very_fast_ale`: warm range from the yeast preset; no automatic D-rest by default.
- `high_attenuation_saison`: warm, gently rising profile toward the upper yeast range; no classic D-rest by default.

Style modifiers stay intentionally light:

- Hoppy styles enable dry-hop/cold-hop action logic and block cold crash until hop handling is resolved.
- Wheat, stout, and porter may shift main target slightly, but never outside yeast limits.
- Cider, mead, and other styles use Generic + Edit.

## Data Model

`profile.json` receives a versioned `temperatureProfile` object.

Core fields:

- `version`
- `family`
- `presetId`
- `source`
- `phases`
- `advanced`
- `status`

Phase fields:

- `id`
- `label`
- `targetC`
- `holdHoursAfterReached`
- `triggerType`
- `rampClass`
- `requiresActionResolved`
- `autoStartPolicy`

Status fields:

- `activePhaseId`
- `targetReached`
- `targetReachedAt`
- `phaseStartedAt`
- `autoStarted`

Advanced fields:

- `pitchC`
- `mainC`
- `dRestC`
- `crashC`
- `lagerC`
- `mainHoldHours`
- `dRestHoldHours`
- `crashHoldHours`
- `targetCO2`
- `carbonationC`
- `carbonationDays`
- `storageC`
- `storageDaysHint`

Legacy behavior:

- Batches without `temperatureProfile` are not migrated automatically.
- The current min/max midpoint target remains the fallback.
- CSV history and old `profile.json` files must remain readable.

## Wizard

Default compact flow:

1. Select beer style.
2. Select yeast preset or custom yeast.
3. Wizard generates the temperature profile automatically.
4. Wizard shows a compact summary: pitch, main, D-rest if present, crash, lager/package hint.
5. If a paired Plug is available, offer Plug Auto Mode.
6. Advanced allows editing the core temperatures, hold times, and target CO2.

Wizard rules:

- Yeast profile is authoritative.
- Beer style may only apply small modifiers within yeast limits.
- Plug Auto Mode selects Plug beer probe as the authoritative temperature for Base display, logging, and analysis.
- If Plug is not available, the temperature profile remains advisory.

## Hybrid Phase Logic

Temperature phases are not advanced by elapsed recipe time alone.

Biological gates:

- SG trend
- fermentation phase
- attenuation / FG stability
- batch actions such as dry hop, cold hop, D-rest, cold crash, package

Temperature stability gates:

- Plug beer sensor reaches target.
- Target remains within tolerance for the phase hold time.
- Plug status is fresh.
- Latest Plug command was acknowledged by the Plug or fresh Plug status confirms the requested target.

Auto-start policy:

- D-rest may auto-start when fermentation status fits, Plug is fresh, and the Plug has acknowledged the latest target command or reports the requested target.
- Cold crash may auto-start when D-rest is resolved, hop actions are resolved, FG is stable, Plug is fresh, and the Plug has acknowledged the latest target command or reports the requested target.
- Package remains manual.
- After manual package confirmation, SGNode may enter a post-package temperature-support mode for carbonation and storage.

Important naming decision:

- A future implementation should distinguish `coldCrashStarted` from `coldCrashDone`.
- The current profile model uses action acknowledgement fields that are too ambiguous for automatic cold-crash control.

## Plug Control Boundary

Base sends:

- requested beer target
- ramp intent / ramp class
- batch size
- controller parameters when explicitly configured
- post-package air-only target when the batch is packaged and the beer probe is no longer available

Plug controls locally:

- beer probe is the controlled process value
- fridge-air probe is the inner two-point control value
- PI / D-brake / anti-windup derives fridge-air target
- relay timing and compressor protection remain local
- in post-package air-only mode, the beer probe is ignored and the fridge-air probe directly controls the relay around the requested air target

Base displays and logs:

- Plug beer temperature as primary temperature when Plug Auto Mode is active
- Float temperature as diagnostic `float_temperature`
- requested beer target
- derived air target
- relay state and 10-minute duty
- controller state and faults
- post-package air-only phase, air target, air actual, and duty even when Float packets are absent

## Post-Package Temperature Support

Package itself remains manual: the user confirms that bottling/kegging is done.

After confirmation, SGNode may continue the same batch in a post-package phase:

- `carbonation`: hold fridge air at the carbonation temperature for the configured duration.
- `storage` / `lagering`: move to the configured storage temperature after carbonation time has elapsed.

Control source changes:

- Beer/vessel probe is expected to be unavailable after packaging.
- Float may be unavailable or out of radio range.
- Plug switches to air-only control using the fridge-air DS18B20.
- Base no longer treats missing Float or missing Plug beer probe as a blocker for post-package temperature support.

Logging changes:

- During fermentation, combined CSV rows can remain Float-triggered.
- During post-package air-only mode, Base must also be able to append Plug-timed rows, ideally every 10 minutes.
- Post-package rows leave SG, angle, Float battery, and Float temperature empty or sentinel-coded, while Plug air temperature, air target, relay state, duty, and faults remain populated.
- CSV readers must distinguish measurement source/state so post-package air-only rows do not corrupt SG/attenuation charts.
- The batch remains active for temperature support until the user ends tracking or the storage period is complete.

UI changes:

- Package screen shows sugar and carbonation guidance before confirmation.
- After confirmation, Dashboard shows `Carbonation` or `Storage` instead of fermentation phase.
- Live/Details show Plug Air as the controlled value and mark Beer/Float as unavailable rather than stale failure.
- Manage Brew must allow ending post-package tracking manually.

## Plug-Test Dependency

The current `plug_test_schedule` is only a validation tool. It will be replaced by the real `temperatureProfile` model after tuning.

Current 13 L water/fridge validation goals:

- Start from a clean stable beginning, not the disturbed warm-water recovery section.
- SG-vs-temperature analysis starts only with the new clean test data.
- 22 -> 12 C: delay, cooling rate, air minimum, duty, undershoot/overshoot.
- 12 -> 4 C: cold-crash behavior, clamp behavior, duty, reachable air target.
- 4 -> 15 C: passive warming, residual cooling, overshoot risk.

Values to keep validating from test data:

- normal ramp default
- cold-crash ramp default
- absolute air target minimum
- whether static/dynamic offset clamps are needed or can be replaced by tuned PI + D-brake behavior
- `Kp`, `Tn`, D-brake defaults across other fill levels
- batch-size-to-`Tn` scaling
- beer-temperature smoothing window

Do not derive permanent defaults from:

- manually disturbed warm-water mixing
- open-fridge periods
- missing Plug sensors during bench flashing
- Float/BMI chip temperature

## Packaging Guidance

Packaging guidance is generated from style and Advanced settings.

Package screen should show:

- sugar grams per 0.5 L bottle
- total sugar amount
- target CO2
- carbonation temperature
- carbonation duration hint
- lagering/storage hint where useful

v1 assumptions:

- household sugar / sucrose
- manual package confirmation
- active post-package temperature support is allowed when Plug is enabled
- 0.5 L bottles plus total batch quantity are the primary output

## Test Plan

Profile generation:

- Every built-in yeast preset maps to the expected profile family.
- Custom yeast uses `curveTemplate`, min/max temperature, fermentation speed, and D-rest flag.
- Cider, mead, and other styles use Generic + Edit.

Wizard:

- Compact view shows the generated profile correctly.
- Advanced stores core values in `profile.json`.
- Legacy batches without `temperatureProfile` remain unchanged.

Control integration:

- Base sends the correct beer target for the active phase.
- Plug beer temperature replaces Float temperature for Plug Auto batches in Live, Dashboard, Graph, and new CSV rows.
- Float temperature remains logged as `float_temperature`.
- Post-package Plug air-only rows are logged every 10 minutes even when Float packets are absent.
- Plug test schedule does not leak into normal batch profile behavior.

Actions:

- Dry hop blocks cold crash until done, removed, or skipped.
- D-rest and cold crash start only when all biological and Plug gates are satisfied.
- Package shows sugar and carbonation recommendation.
- After Package confirmation, Plug air-only mode supports carbonation and storage temperatures.

Regression:

- Arduino compile Base and Plug.
- Batch start gating stays stable.
- Manage Brew stays usable.
- Existing CSV history remains readable.
- SG/attenuation charts ignore post-package air-only rows.
- Old batches without temperature profiles keep legacy behavior.

## Assumptions

- Yeast profile is the main source; style is a modifier.
- All existing presets receive v1 temperature profiles.
- Old batches are not auto-migrated.
- Initial Plug controller defaults are based on the first 13 L water/fridge validation. Broader ramp/profile defaults still need more validation across fill levels and real fermentation heat.
- Packaging starts as guidance, then may continue as Plug-supported carbonation/storage temperature management after manual confirmation.
- Priming output focuses on 0.5 L bottles plus total amount.

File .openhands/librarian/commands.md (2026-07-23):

# SGNode Commands Reference

## Build Commands

**Note:** SGNode uses Arduino IDE for compilation. No CLI build system available.

| Task | Command/Steps | Notes |
|---|---|---|
| **Build Base** | Arduino IDE → Sketch → Verify/Compile `SGNode_Base.ino` | Select ESP32 board |
| **Build Float** | Arduino IDE → Sketch → Verify/Compile `SGNode_Float.ino` | Select ESP32 board |
| **Build Plug** | Arduino IDE → Sketch → Verify/Compile `SGNode_Plug.ino` | Select ESP8266 board |
| **Flash Base** | Arduino IDE → Sketch → Upload | USB connection required |
| **Flash Float** | Arduino IDE → Sketch → Upload | USB connection required |
| **Flash Plug** | Arduino IDE → Sketch → Upload | USB connection required |

### Build Prerequisites
1. Arduino IDE 2.x
2. ESP32 board support package
3. ESP8266 board support package
4. Libraries: `TFT_eSPI`, `XPT2046_Touchscreen`, `EmotiBit BMI160`, `OneWire`, `DallasTemperature`

## Test Commands

**Note:** No automated test system. Manual testing only.

| Task | Method | Notes |
|---|---|---|
| **Unit Tests** | None | No testing framework |
| **Integration Tests** | Manual testing with hardware | Use test harness in `SGNode_Base/src/test/` |
| **Serial Debug** | `#define SGNODE_DEBUG_LEVEL DEBUG_INFO` in `SGNode_Base.ino` | Levels: QUIET, ERROR, INFO, VERBOSE |

## Lint/Format Commands

**Note:** No linting or formatting tools available.

| Task | Tool/Method | Notes |
|---|---|---|
| **Lint** | None | Arduino IDE compilation catches syntax errors |
| **Format** | None | Manual formatting |

## Development Start

| Task | Command/Steps | Notes |
|---|---|---|
| **Start Development** | Open `SGNode_Base/SGNode_Base.ino` in Arduino IDE | Base is primary development focus |
| **Enable Debug** | Set `SGNODE_DEBUG_LEVEL` in main sketch | Use `DEBUG_INFO` for setup, `DEBUG_VERBOSE` for diagnostics |

## Serial Commands

### Base Station Debug Output
```cpp
// In SGNode_Base.ino, set debug level:
#define SGNODE_DEBUG_LEVEL DEBUG_INFO  // or QUIET, ERROR, VERBOSE
```

### Float Test Harness
```cpp
// In SGNode_Float.ino, enable test mode:
#define SGNODE_FLOAT_TEST_HARNESS 1  // Mock sensors, pause state machine
```

## Hardware Interaction

| Task | Method | Notes |
|---|---|---|
| **Zero Calibration** | Dashboard → Level Float → READY → Put Float In Brew → DONE | Must confirm before logging |
| **SG Calibration** | More → Calibration → Record points → Apply polynomial | Stored in float EEPROM |
| **SD Card** | FAT32, inserted before boot | Paths: `/data/batches/`, `/data/yeast/` |
| **RTC** | Optional DS323x on GPIO32/25 | Improves timestamp stability |

## Debug Output

**Base Station:** Serial at 115200 baud

**Debug Levels:**
- `DEBUG_QUIET` - No serial output
- `DEBUG_ERROR` - Only errors
- `DEBUG_INFO` - Setup details (use for MAC address)
- `DEBUG_VERBOSE` - Packet/SD/graph diagnostics

**Use Cases:**
- Setup: `DEBUG_INFO` for MAC address, ESP-NOW pairing
- Troubleshooting: `DEBUG_VERBOSE` for packet loss, SD issues

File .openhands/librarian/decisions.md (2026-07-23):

# SGNode Architectural Decisions

## Protocol Design

### ESP-NOW Payload Versioning
**Decision:** Protocol version 2 with CRC16-CCITT checksums.

**Rationale:** Ensures compatibility across Base/Float/Plug and detects transmission errors.

**Impact:** Changing payload structure requires version bump and coordinated firmware updates.

### Polynomial Calibration in Float EEPROM
**Decision:** Store cubic polynomial coefficients in float's EEPROM for SG calibration.

**Rationale:** Float owns calibration; coefficients persist across reboots and don't need base intervention.

**Impact:** Changing calibration algorithm requires EEPROM format migration strategy.

## Temperature Control

### PI Controller with D-Brake
**Decision:** Implement PI control with derivative brake (D-brake) in Plug.

**Rationale:** Prevents compressor overshoot and short-cycling while maintaining target stability.

**Impact:** PI parameters (Kp, Tn, D-brake) are critical for hardware safety.

### Beer Probe vs Air Probe Control
**Decision:** Use beer probe as primary feedback, calculate air target from PI output.

**Rationale:** Direct beer temperature control yields better fermentation profiles.

**Impact:** Air-only mode (post-package) is fallback when beer probe unavailable.

## Fermentation State Machine

### Phase Transitions
**Decision:** Driven by biological gates (SG trend, attenuation) and temperature stability, not elapsed time alone.

**Rationale:** Fermentation biology varies; automated transitions adapt to actual process.

**Impact:** User may need to manually advance phases if data is incomplete.

### Auto-Start Policies
**Decision:** D-rest and cold crash auto-start only when biological gates AND Plug status gates satisfied.

**Rationale:** Temperature control must be reliable before automatic phase changes.

**Impact:** Plug communication failures block automatic progression.

## Data Persistence

### SD Card Format
**Decision:** FAT32, JSON for metadata (profile.json, target.json), CSV for logs.

**Rationale:** Simple, portable, readable, works with standard tools.

**Impact:** Changing format requires migration strategy or backward compatibility.

### Batch Lifecycle
**Decision:** Batch starts only after "Put Float In Brew" confirmation.

**Rationale:** Prevents handling/air measurements from contaminating batch history.

**Impact:** Float packets before confirmation update live display but not CSV log.

## UI Design

### No External Connectivity
**Decision:** No web UI, phone app, or cloud. All functionality on touchscreen base.

**Rationale:** Self-contained, offline, no network dependencies, privacy-friendly.

**Impact:** No remote access, no data sync, no mobile convenience.

### Theme System
**Decision:** Light/dark theme with persistent setting.

**Rationale:** User preference and usage conditions (low light).

**Impact:** Theme state stored in EEPROM/SD, not memory-only.

## Power Management

### Float Deep Sleep
**Decision:** Deep sleep between measurements (configurable interval 60-600s).

**Rationale:** Battery-powered float must maximize sleep time.

**Impact:** Measurement interval affects data resolution and battery life.

### Zero Calibration
**Decision:** Two separate systems: polynomial SG calibration (manual) and zero-cal (automatic via ACK).

**Rationale:** Different purposes: SG from known solutions vs tilt orientation.

**Impact:** Zero-cal happens automatically during batch start; polynomial requires user interaction.

## Build System

### Arduino IDE Only
**Decision:** No CLI build system. Use Arduino IDE for compilation and upload.

**Rationale:** ESP32/ESP8266 ecosystem standard, simpler for hobbyist users.

**Impact:** CI/CD automation requires special setup or manual process.

## Debug Strategy

### Debug Levels
**Decision:** Four levels: QUIET, ERROR, INFO, VERBOSE.

**Rationale:** Balance between diagnostics and production noise.

**Impact:** Set via preprocessor define; not runtime-configurable.

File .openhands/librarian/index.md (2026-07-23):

# SGNode Project Overview

## What is SGNode?

ESP32-based fermentation monitoring and temperature control for brewing (beer/wine/cider/mead). Self-contained system with no cloud/phone app.

**Status:** alpha 0.5.0 (Float/Base tested; Plug awaiting water/fridge validation)

## Architecture

```
SGNode_Base (ESP32) ──ESP-NOW── SGNode_Float (ESP32)
                      │
                      └──ESP-NOW── SGNode_Plug (ESP8266)
```

- **Base:** 4" touchscreen, SD card, receives float data, displays charts/UI
- **Float:** Battery-powered, BMI160 IMU tilt sensor, deep sleep, ESP-NOW TX
- **Plug:** ESP8285 smart plug, DS18B20 sensors, PI control, relay output

## Core Components

### SGNode_Shared/
- `sg_protocol.h` - ESP-NOW payload format (v2), command/status structures, CRC16
- `plug_hardware.h` - Plug pin assignments, relay control helpers

### SGNode_Base/src/
- `ui/` - Brew Wizard, touchscreen UI components
- `domain/` - Batch model, yeast presets, state machine, recommendations
- `calculations/` - Brix/SG conversion, ETA, OG verification, target curves
- `test/` - Optional UI test harness

### SGNode_Float/
- `polynomial_calibration.h` - SG calibration from tilt (EEPROM-stored)
- Deep sleep between measurements, retry buffer for missed ACKs

### SGNode_Plug/src/
- `plug_sensors.cpp` - DS18B20 temperature reading
- `beer_pi_controller.cpp` - PI control with D-brake, anti-windup
- `air_controller.cpp` - Fridge air target calculation
- `relay_history.cpp` - Duty cycle tracking

## Data Flow

1. Float measures tilt/temp/battery → sends ESP-NOW packet to base
2. Base receives, calculates SG/attenuation, logs to SD (CSV)
3. Plug receives beer target from base → controls relay via PI algorithm
4. User interacts via base touchscreen (Live, Graph, Dashboard, More views)

## Persistence

- **SD card:** `/data/batches/<id>/` with `profile.json`, `target.json`, `log.csv`
- **Yeast:** `yeast/` directory with custom presets, `yeasts.txt` index
- **EEPROM (Float):** Polynomial coefficients, zero-cal offset

## Key Protocols

- **ESP-NOW:** Channel 1, CRC16-CCITT checksums, sequence numbers
- **Calibration:** Polynomial (cubic) SG from tilt, zero-cal via ACK commands
- **Communication:** Base→Float (ACK with commands), Base↔Plug (command/status)

## Build & Flash

- **Arduino IDE 2.x** required (no CLI build system)
- Base: ESP32 board, Float: ESP32 board, Plug: ESP8266 board
- Libraries: TFT_eSPI, XPT2046_Touchscreen, EmotiBit BMI160, OneWire, DallasTemperature

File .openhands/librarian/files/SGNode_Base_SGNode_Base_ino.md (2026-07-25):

# SGNode_Base/SGNode_Base.ino

**Type:** Arduino Sketch
**Hash:** `13bce0a2e95b785e0de0d517c402f774edc6f345c7a4d577b6123963380441d2`

## Overview / Role

Core functionality module

## Verified API & Symbols

### Structs & Classes

- `struct Theme`
  - `uint16_t background`
  - `uint16_t cardBackground`
  - `uint16_t buttonInactive`
  - `uint16_t primary`
  - `uint16_t primaryText`
  - `uint16_t accent`
  - `uint16_t accentText`
  - `uint16_t gold`
  - `uint16_t textPrimary`
  - `uint16_t textSecondary`
  - `uint16_t textMuted`
  - `uint16_t success`
  - `uint16_t warning`
  - `uint16_t error`
  - `uint16_t info`
  - `uint16_t border`
  - `uint16_t gridLine`
  - `uint16_t graphPurple`
  - `uint16_t graphBlue`
  - `uint16_t graphGreen`

- `struct BufferedData`
  - `payload_t data`
  - `uint32_t epoch_s`
  - `unsigned long buffered_millis`
  - `bool written`

- `struct GraphPoint`
  - `int x`
  - `int y`
  - `bool valid`

- `struct PlugGovernorSettings`
  - `float kp`
  - `float integralTnHours`
  - `float dBrakeHours`
  - `float airTurnOffAboveTargetC`
  - `float airTurnOnAboveTargetC`
  - `uint16_t airMinimumOnS`
  - `uint16_t airMinimumOffS`
  - `float coldIntegralBandC`
  - `float warmIntegralBandC`
  - `float maxPositiveIntegralC`
  - `float maxNegativeIntegralC`
  - `float integralLeakPerHour`
  - `float errorCrossingKeepFactor`
  - `float maxDOffsetC`
  - `float warmingDFactor`
  - `float beerUndershootLockoutC`
  - `float fastWarmingRateKPerH`
  - `float strongUndershootC`
  - `float strongUndershootAirOffsetC`
  - `float minAirTargetC`
  - `float maxAirTargetC`
  - `float targetStepC`
  - `float rampControllerKpHours`
  - `float rampControllerTnHours`
  - `float maxRampTrimC`
  - `float rampFadeDistanceC`
  - `float rateFilterSamples`

- `struct PlugTestPhase`
  - `float targetC`
  - `uint32_t holdSeconds`
  - `float minBeerC`
  - `bool hasMinBeerC`

- `struct UITestObject`
  - `const char* id`
  - `const char* type`
  - `const char* label`
  - `int x`
  - `int y`
  - `int w`
  - `int h`
  - `bool enabled`
  - `bool visible`

- `struct EditableYeastPreset`
  - `char id[24]`
  - `char displayName[32]`
  - `char category[32]`
  - `int typicalAttenuationMin`
  - `int typicalAttenuationMax`
  - `int defaultAttenuation`
  - `char fermentationSpeed[16]`
  - `float lagPhaseHours`
  - `float typicalDurationHours`
  - `float recommendedTempMinC`
  - `float recommendedTempMaxC`
  - `char flocculation[16]`
  - `char curveTemplate[32]`
  - `bool diacetylRestRecommended`
  - `char notes[64]`

- `struct ManagedBatchSummary`
  - `bool loaded`
  - `bool completed`
  - `bool postPackageTracking`
  - `char style[24]`
  - `float liters`
  - `int points`
  - `uint32_t firstEpoch`
  - `uint32_t lastEpoch`
  - `char status[18]`
  - `char evaluation[32]`

### Functions

- `void setup (void)`

- `void loop (void)`

- `void bcdToDec (uint8_t value)`

- `void decToBcd (uint8_t value)`

- `void daysFromCivil (int year, unsigned month, unsigned day)`

- `void dateTimeToEpoch (uint16_t year, uint8_t month, uint8_t day, uint8_t hour, uint8_t minute, uint8_t second)`

- `void civilFromDays (int64_t z, uint16_t* year, uint8_t* month, uint8_t* day)`

- `void epochToDateTime (uint32_t epoch, uint16_t* year, uint8_t* month, uint8_t* day, uint8_t* hour, uint8_t* minute, uint8_t* second)`

- `void isEpochValid (uint32_t epoch)`

- `void compileMonthNumber (const char* monthName) const`

- `void buildEpochWithUploadOffset (void)`

- `void readRTCDateTime (uint16_t* year, uint8_t* month, uint8_t* day, uint8_t* hour, uint8_t* minute, uint8_t* second)`

- `void setRTCDateTime (uint16_t year, uint8_t month, uint8_t day, uint8_t hour, uint8_t minute, uint8_t second)`

- `void getCurrentEpoch (void)`

- `void formatTimestamp (uint32_t epoch, char* buf, size_t bufSize)`

- `void parseDateTimeToEpoch (const char* timestamp) const`

- `void syncSystemTimeFromRTC (uint32_t epoch)`

- `void initRTC (void)`

- `void initESPNow (void)`

- `void esp_now_register_recv_cb ([](const esp_now_recv_info_t *recv_info, const uint8_t *data, int len) const`

- `void setFloatZeroCalStatus (const char* message) const`

- `void sendDataAck (const uint8_t* mac, const payload_t& data) const`

- `void isDuplicateFloatSequence (uint16_t sequence_id)`

- `void rememberFloatSequence (uint16_t sequence_id)`

- `void initDisplay (void)`

- `void drawCurrentScreen (void)`

- `void initTouch (void)`

- `void ensureFloatPeerRegistered (const uint8_t* mac) const`

- `void onPlugStatusReceived (const uint8_t *mac, const uint8_t *incomingData, int len) const`

- `void hasValidPlugBeerTemperature (void)`

- `void currentPlugBeerTemperatureC (void)`

- `void hasValidPlugAirTemperature (void)`

- `void hasFreshPlugStatus (void)`

- `void usesPlugTemperatureAsPrimary (void)`

- `void isPostPackageTemperaturePhase (void)`

- `void isFloatInactiveAfterPackaging (void)`

- `void shouldShowFloatStillActiveWarning (void)`

- `void effectiveTemperatureC (float floatTemperatureC)`

- `void latestDisplayedTemperatureC (void)`

- `void sendPlugCommandIfDue (void)`

- `void onDataReceived (const uint8_t *mac, const uint8_t *incomingData, int len) const`

- `void addDataPoint (payload_t data, uint32_t epoch_s)`

- `void clearHistoricalDisplayData (void)`

- `void clearBufferedSensorData (void)`

- `void shouldRecordBatchFloatData (void)`

- `void finalizeHistoricalDataLoad (void)`

- `void markScreenDirtyForFloatData (void)`

- `void displayBufferIndexForPoint (int pointIndex)`

- `void timestampForPoint (int pointIndex)`

- `void timestampsAvailableForGraph (void)`

- `void graphXForPoint (int pointIndex, int graphX, int graphW)`

- `void calculateTimestampTrend (float latestDensity, uint32_t latestEpoch, float* trendOut)`

- `void drawLiveViewStatic (void)`

- `void updateLiveViewDynamic (void)`

- `void drawFloatOffAngleTile (int x, int y, int w, int h)`

- `void drawLiveView (void)`

- `void drawGraphView (void)`

- `void drawRecommendationPanel (int x, int y, int w, int h)`

- `void formatActionHeader (char* buffer, size_t bufferSize)`

- `void drawDashboardScreen (void)`

- `void copyPresetToDraft (const YeastPreset* preset) const`

- `void optionIndex (const char* value, const char* const* options, int count) const`

- `void selectOptionOffset (char* target, size_t targetSize, const char* const* options, int count, int offset) const`

- `void beginNewYeastWizard (const char* presetId) const`

- `void loadYeastStepBuffer (void)`

- `void commitYeastStepBuffer (void)`

- `void drawNewYeastNav (const char* nextLabel) const`

- `void drawYeastDropdown (const char* label, const char* value) const`

- `void drawNewYeastScreen (void)`

- `void saveNewYeastWizard (void)`

- `void handleNewYeastTouch (int x, int y)`

- `void loadManagedYeasts (void)`

- `void drawManageYeastScreen (void)`

- `void handleManageYeastTouch (int x, int y)`

- `void batchNumberFromId (const char* id) const`

- `void loadManagedBatches (void)`

- `void nextBatchNumberOnSD (void)`

- `void continueManagedBatch (const char* batchId) const`

- `void copyManagedBatch (const char* batchId) const`

- `void buildManagedBatchChildPath (const char* parentPath, const char* entryName, char* path, size_t pathSize) const`

- `void deleteManagedBatchPath (const char* path) const`

- `void deleteManagedBatch (const char* batchId) const`

- `void markManagedBatchCompleted (const char* batchId) const`

- `void loadManagedBatchSummary (const char* batchId, ManagedBatchSummary* summary) const`

- `void drawManageBrewScreen (void)`

- `void handleManageBrewTouch (int x, int y)`

- `void drawBrewWizardScreen (void)`

- `void drawOGVerificationScreen (void)`

- `void targetChartHours (void)`

- `void temperatureChartHours (void)`

- `void postPackageTemperatureStartEpoch (void)`

- `void postPackageTemperatureStartHour (void)`

- `void postPackageTemperatureChartHours (void)`

- `void targetStartOffsetHours (void)`

- `void fermentationElapsedSecondsAt (unsigned long epoch)`

- `void targetModelHourForChartHour (float chartHour)`

- `void targetChartHourForModelHour (float modelHour)`

- `void expectedTargetSGAtChartHour (float chartHour)`

- `void resetPlugTestScheduleState (void)`

- `void parseJsonNumberAfter (const char* start, const char* key, float fallback) const`

- `void boundedOrDefault (float value, float fallback, float minimum, float maximum)`

- `void boundedSecondsOrDefault (float value, uint16_t fallback, uint16_t minimum, uint16_t maximum)`

- `void normalizePlugGovernorSettings (void)`

- `void resetPlugGovernorSettingsToDefaults (void)`

- `void savePlugGovernorSettingsToSD (void)`

- `void ensurePlugGovernorSettingsLoaded (void)`

- `void plugGovernorSettingLabel (uint8_t index)`

- `void plugGovernorSettingValue (uint8_t index)`

- `void setPlugGovernorSettingValue (uint8_t index, float value)`

- `void plugGovernorSettingStep (uint8_t index)`

- `void formatPlugGovernorSettingValue (uint8_t index, char* buffer, size_t bufferSize)`

- `void adjustPlugGovernorSetting (int direction)`

- `void loadPlugTestScheduleIfNeeded (void)`

- `void plugTestScheduleTargetC (float fallbackTarget, unsigned long nowEpoch)`

- `void legacyTemperatureTargetC (unsigned long nowEpoch)`

- `void currentTemperaturePhase (unsigned long nowEpoch)`

- `void currentTemperatureTargetC (unsigned long nowEpoch)`

- `void currentTemperatureRampKPerHour (unsigned long nowEpoch)`

- `void currentDisplayPhaseName (unsigned long nowEpoch)`

- `void targetHourForSG (float targetSG, float chartHours)`

- `void targetHourForAttenuation (float attenuationPercent, float chartHours)`

- `void eventHourFromEpoch (unsigned long eventEpoch)`

- `void graphXForHour (float hour, int graphX, int graphW, float chartHours)`

- `void rampedProfileTemperatureAtHour (float hour, TemperatureProfileRuntimePhase* phaseOut)`

- `void pointHourForBatchChart (int pointIndex)`

- `void drawTargetEventMarker (int gx, int gy, int gw, int gh, float chartHours, float hour, const char* label, uint16_t color, int labelSlot, int labelSide) const`

- `void drawTargetChartSpanLabel (int gx, int gy, int gw, float chartHours, float startHour, float endHour, const char* label, uint16_t color, int row) const`

- `void drawTargetChartXAxis (int gx, int gy, int gw, int gh, float chartHours)`

- `void drawTargetChartEventMarkers (int gx, int gy, int gw, int gh, float chartHours, bool includePostPackage)`

- `void drawPostPackageTemperatureEventMarkers (int gx, int gy, int gw, int gh, float chartHours)`

- `void drawTargetVsActualChart (void)`

- `void drawGrid (int graphX, int graphY, int graphW, int graphH, float minDensity, float maxDensity)`

- `void drawGraphLine (int x0, int y0, int x1, int y1, uint16_t color)`

- `void angleForTargetSG (float targetSG)`

- `void drawGraph (void)`

- `void drawGraphForMetric (GraphMetric metric)`

- `void drawCalibrationView (void)`

- `void drawBatteryView (void)`

- `void drawTempGraphView (void)`

- `void drawTempGraphModeToggle (int contentY)`

- `void drawAngleGraphView (void)`

- `void drawAbvGraphView (void)`

- `void drawButton (int x, int y, int w, int h, const char* label, bool active) const`

- `void drawThemeToggle (int x, int y, bool enabled)`

- `void loadThemePreference (void)`

- `void saveThemePreference (void)`

- `void toggleTheme (void)`

- `void isLogoBackgroundPixel (uint16_t color)`

- `void loadBacklightPreference (void)`

- `void saveBacklightPreference (void)`

- `void applyBacklightLevel (void)`

- `void initBacklight (void)`

- `void cycleBacklightLevel (void)`

- `void baseOtaDiagHtml (void)`

- `void baseOtaPageHtml (void)`

- `void syncTime (void)`

- `void then (function(r)`

- `void then (function(t)`

- `void startBaseOtaMode (void)`

- `void on ("/", HTTP_GET, []()`

- `void on ("/diag", HTTP_GET, []()`

- `void on ("/logo.png", HTTP_GET, []()`

- `void on ("/reboot", HTTP_GET, []()`

- `void on ("/settime", HTTP_GET, []()`

- `void on ("/update", HTTP_POST, []()`

- `void stopBaseOtaAndReboot (void)`

- `void handleBaseOtaMode (void)`

- `void drawCenteredDialogFrame (int boxX, int boxY, int boxW, int boxH)`

- `void drawBaseOtaScreen (void)`

- `void drawBaseOtaConfirmDialog (void)`

- `void drawFloatOtaPopup (void)`

- `void drawTopbarPulldown (void)`

- `void handleOverlayTouch (int x, int y)`

- `void onFloatOtaStatusReceived (const uint8_t* mac, const uint8_t* data, int len) const`

- `void drawBootScreen (void)`

- `void checkTouch (void)`

- `void sendCalibrationCommand (uint8_t command, float target_sg)`

- `void applyCalibration (void)`

- `void sendExitCalibrationCommand (void)`

- `void abortCalibrationFlow (void)`

- `void onCalibrationResponse (const uint8_t *mac, const uint8_t *incomingData, int len) const`

- `void onCalibrationCoefficients (const uint8_t *mac, const uint8_t *incomingData, int len) const`

- `void onCalibrationCommandFromFloat (const uint8_t *mac, const uint8_t *incomingData, int len) const`

- `void copyCsvField (const char* line, int fieldIndex, char* out, size_t outSize) const`

- `void parseCsvFloatField (const char* line, int fieldIndex, float* valueOut) const`

- `void isPlausibleCsvBeerTemperature (float value)`

- `void isFermentationCsvDataPoint (const payload_t& data) const`

- `void isPostPackageCsvTemperaturePoint (const payload_t& data, uint32_t epoch_s) const`

- `void parsePostPackageCsvTemperaturePoint (const char* line, payload_t* data, uint32_t* epoch_s, uint8_t* battery_percent, float* temperatureOut) const`

- `void clearPostPackageTemperatureGraphData (void)`

- `void appendPostPackageTemperatureGraphData (uint32_t epoch_s, float temperatureC)`

- `void loadPostPackageTemperatureGraphData (void)`

- `void parseCSVDataLine (const char* line, payload_t* data, uint32_t* epoch_s, uint8_t* battery_percent) const`

- `void loadHistoricalDataFromCSV (const char* filename, GraphLoadMode mode, int maxPoints, int samplingStep) const`

- `void formatDurationShort (unsigned long seconds, char* buffer, size_t bufferSize)`

- `void startNewBatchStorage (const char* batchId) const`

- `void ensureFermentationLogFile (const char* batchId) const`

- `void createFreshBatchLogFile (const char* batchId) const`

- `void rollbackBatchFiles (const char* batchId) const`

- `void findBestFallbackBatch (char* batchId, size_t bufferSize)`

- `void persistActiveBrewProfile (void)`

- `void beginBrewWizard (void)`

- `void cancelBrewWizard (void)`

- `void completeBrewWizard (void)`

- `void handleOGChoice (bool useMeasuredOG)`

- `void handleCurrentActionChoice (bool done)`

- `void saveYeastPerformanceSummary (float finalGravity, uint32_t completedAt)`

- `void isPlausibleSensorReading (const payload_t& data, const char** issue) const`

- `void updateFermentationAssistant (payload_t data, uint32_t epoch_s)`

- `void refreshCurrentBatchAction (float currentSG, unsigned long nowEpoch)`

- `void evaluateBatchActionWithHysteresis (FermentationPhase phase, float attenuation, float currentSG, float gravityDeltaPerHour, unsigned long nowEpoch)`

- `void autoStartColdCrashIfPlugReady (unsigned long nowEpoch)`

- `void shouldKeepDryHopActionLatched (const BatchAction& previousAction, const BatchAction& nextAction, float currentSG, float gravityDeltaPerHour) const`

- `void makeLatchedDryHopAction (float currentSG)`

- `void smoothedGravityDeltaPerHour (int maxReadings)`

- `void refreshFermentationAssistantFromProfile (void)`

- `void migrateActiveBrewProfileFromHistory (const char* logPath) const`

- `void checkExistingFermentation (void)`

- `void createNewFermentationFile (void)`

- `void logDataToSD (payload_t data, uint32_t epoch_s)`

- `void logPostPackagingTemperatureIfDue (void)`

- `void drawCreateNewDialog (void)`

- `void logOGToSD (void)`

- `void checkOGStability (float currentSG)`

- `void calculateABV (float og, float currentSG)`

- `void calculateBatteryPercentage (float voltage)`

- `void getLatestDisplayBatteryVoltage (float* voltageOut)`

- `void drawViewTopbar (const char* title) const`

- `void shouldShowSdWarning (void)`

- `void drawSdWarningTopbar (void)`

- `void loadAllHistoryForDetailChart (void)`

- `void drawNoDataCard (const char* message, const char* subtext, int activeTab) const`

- `void drawDetailSection (int* y, const char* title) const`

- `void drawDetailRow (int* y, const char* label, const char* value) const`

- `void drawDetailSectionAt (int x, int* y, int w, const char* title) const`

- `void drawDetailRowAt (int x, int* y, int w, const char* label, const char* value) const`

- `void drawWrappedText (int x, int y, int w, const char* text, uint16_t color) const`

- `void updateChargingState (float currentVoltage)`

- `void calculateDischargeRateLinearRegression (void)`

- `void drawMoreView (void)`

- `void drawLiveDetailsView (void)`

- `void drawPlugGovernorView (void)`

- `void handleLiveDetailsTouch (int x, int y)`

- `void handlePlugGovernorTouch (int x, int y)`

- `void mountSDTemporarily (void)`

- `void dismountSD (void)`

- `void bufferSensorData (payload_t data, uint32_t epoch_s)`

- `void writeBufferedDataToSD (void)`

- `void isSafeForSDOperation (void)`

- `void loadFloatMacFromEEPROM (void)`

- `void saveFloatMacToEEPROM (void)`

- `void loadPlugMacFromEEPROM (void)`

- `void savePlugMacToEEPROM (void)`

- `void startWait (int durationMs)`

- `void drawPolynomialGraph (void)`

- `void calculateGraphPoints (void)`

- `void drawGraphAxes (void)`

- `void drawGraphCurve (void)`

- `void calibrationPointCount (void)`

- `void calibrationPointIndex (CalibMode mode)`

- `void calibrationModeForPoint (int index)`

- `void calibrationTargetSG (int index)`

- `void calibrationAddAmount (int index)`

- `void checkWaitTimeout (void)`

- `void stopWait (void)`

- `void formatTimeFromDataPoint (int index, char* buf, int bufSize)`

- `void updateCursorPosition (void)`

- `void drawCursorValueDisplay (int x, int y, bool showRight)`

- `void handleGraphButton6h (void)`

- `void handleGraphButton24h (void)`

- `void handleGraphButtonAll (void)`

- `void handleGraphButtonLeft (void)`

- `void handleGraphButtonRight (void)`

- `void uiTestWizardStepName (BrewWizardStep step)`

- `void uiTestScreenName (void)`

- `void uiTestObjects (UITestObject* objects, int maxObjects)`

- `void uiTestBuildDump (char* buffer, size_t bufferSize)`

- `void uiTestElementMatches (const UITestObject& object, const char* text) const`

- `void uiTestTap (int x, int y)`

- `void uiTestPress (int x, int y)`

- `void uiTestRelease (void)`

- `void uiTestSwipe (int x1, int y1, int x2, int y2, int durationMs)`

- `void uiTestTapLabel (const char* text, int* outX, int* outY) const`

- `void uiTestTapTextKey (char c)`

- `void uiTestTapNumberKey (char c)`

- `void uiTestTypeText (const char* text) const`

- `void uiTestKey (const char* key) const`

- `void uiTestVisibleText (const char* text) const`

- `void uiTestValueEquals (const char* fieldName, const char* expected) const`

- `void uiTestStateEquals (const char* stateName) const`

- `void uiTestSetMockSG (float value)`

- `void uiTestSetMockTemp (float value)`

- `void uiTestSetMockTime (unsigned long value)`

- `void uiTestRunAnalyzer (void)`

- `void uiTestRunStateMachine (void)`

- `void uiTestRunETA (void)`

- `void uiTestRunRecommendations (void)`

- `void uiTestRemoveFileIfExists (const char* path) const`

- `void uiTestDeleteBatchById (const char* batchId) const`

- `void uiTestCreateBatch (void)`

- `void uiTestDeleteBatch (void)`

- `void uiTestMarkTestBatchCompleted (void)`

- `void uiTestBatteryStats (char* buffer, size_t bufferSize)`

- `void uiTestBatchDiagnostics (char* buffer, size_t bufferSize)`

- `void uiTestFloatStats (char* buffer, size_t bufferSize)`

- `void uiTestActionStatus (char* buffer, size_t bufferSize)`

- `void uiTestActionDone (char* buffer, size_t bufferSize)`

- `void uiTestActionSkip (char* buffer, size_t bufferSize)`

- `void uiTestRunActionButtonTests (char* buffer, size_t bufferSize)`

- `void uiTestSelfTest (char* buffer, size_t bufferSize)`

- `void uiTestFileExists (const char* path) const`

- `void uiTestTestBatchFilesExist (bool* profileOK, bool* targetOK, bool* logOK)`

- `void uiTestReadLastLogEpoch (const char* path, uint32_t* epochOut) const`

- `void uiTestWriteMixedEpochLog (const char* path, uint32_t createdAt) const`

- `void uiTestWriteDelayedFermentationLog (const char* path, uint32_t createdAt) const`

- `void uiTestCreateNumberedBatch (int number, const char* name, uint32_t createdAt) const`

- `void uiTestFindHighestBatchWithProfile (void)`

- `void uiTestDeleteNumberedBatch (int number)`

- `void uiTestRunBatchRestoreTests (char* buffer, size_t bufferSize)`

- `void uiTestRunFallbackLogTests (char* buffer, size_t bufferSize)`

- `void uiTestRunCompletedBatchTests (char* buffer, size_t bufferSize)`

- `void uiTestRunManageBrewUITests (char* buffer, size_t bufferSize)`

- `void uiTestPrepareManageBrewComplete (char* buffer, size_t bufferSize)`

- `void uiTestOpenManageBrewCompleteDialog (char* buffer, size_t bufferSize)`

- `void uiTestConfirmManageBrewComplete (char* buffer, size_t bufferSize)`

- `void uiTestPrintResult (bool ok, const char* name, const char* step, const char* expected, const char* actual) const`

- `void uiTestRunOne (const char* name, bool condition, const char* step, const char* expected, const char* actual, int* total, int* passed, int* failed, char* firstFail, size_t firstFailSize) const`

- `void uiTestRegressionValidFloat (float value)`

- `void uiTestRunInputValidationTests (char* buffer, size_t bufferSize)`

- `void uiTestRunSensorEdgeTests (char* buffer, size_t bufferSize)`

- `void uiTestRunStateLogicTests (char* buffer, size_t bufferSize)`

- `void uiTestRunUISafetyTests (char* buffer, size_t bufferSize)`

- `void uiTestRunRegressionTests (char* buffer, size_t bufferSize)`

- `void batteryDebugPrint (bool ok, const char* message) const`

- `void batteryDebugStats (char* buffer, size_t bufferSize)`
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

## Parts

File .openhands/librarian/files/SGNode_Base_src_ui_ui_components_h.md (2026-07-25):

# SGNode_Base/src/ui/ui_components.h

**Type:** C++ Header
**Hash:** `4882adf86370f4d82d7c90e465c5a249882fa6d9a8c113b8238f0cce2f390636`

## Overview / Role

User interface components and rendering

## Verified API & Symbols

### Macros

- `#define UI_COMPONENTS_H #include <Arduino.h>`

## Key Dependencies

**Local:**
- `SGNode_Base/src/ui/ui_tokens.h`

**System/External:**
- `<Arduino.h>`
- `<TFT_eSPI.h>`

## Side Effects & Hardware Access

- Touchscreen UI updates
- SPI bus communication

## Change Risks

- **MEDIUM**: UI changes affect user experience

---
*Last modified (hash): 4882adf86370f4d82d7c90e465c5a249882fa6d9a8c113b8238f0cce2f390636*

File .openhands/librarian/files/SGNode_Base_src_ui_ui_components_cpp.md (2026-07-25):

# SGNode_Base/src/ui/ui_components.cpp

**Type:** C++ Source
**Hash:** `06635495c5c12434af707edcc0300564c792b81aac7252cb1646f26a57818556`

## Overview / Role

User interface components and rendering

## Verified API & Symbols

### Structs & Classes

- `struct Theme`
  - `uint16_t background`
  - `uint16_t cardBackground`
  - `uint16_t buttonInactive`
  - `uint16_t primary`
  - `uint16_t primaryText`
  - `uint16_t accent`
  - `uint16_t accentText`
  - `uint16_t gold`
  - `uint16_t textPrimary`
  - `uint16_t textSecondary`
  - `uint16_t textMuted`
  - `uint16_t success`
  - `uint16_t warning`
  - `uint16_t error`
  - `uint16_t info`
  - `uint16_t border`
  - `uint16_t gridLine`
  - `uint16_t graphPurple`
  - `uint16_t graphBlue`
  - `uint16_t graphGreen`

### Functions

- `void mix565 (uint16_t a, uint16_t b, uint8_t weightB)`

- `void uiInitColors (void)`

- `void uiDrawTopbar (const char* title, bool espNowOk, bool sdOk, uint8_t battPercent) const`

- `void uiNavHitTest (int x, int y)`

- `void uiDrawBottomNav (int activeTab)`

- `void uiCard (int x, int y, int w, int h, int r)`

- `void uiTile (int x, int y, int w, int h, int icon, const char* label, const char* value, const char* unit, bool muted) const`

- `void uiHeroSG (int x, int y, int w, int h, float sgValue, const char* trendText, float* sparklineData, int sparklineCount) const`

- `void uiDrawSparkline (int x, int y, int w, int h, float* data, int count)`

- `void uiTextCenter (int x, int y, int w, int h, const char* text, const GFXfont* font, uint16_t color) const`

- `void uiTextRight (int x, int y, int w, int h, const char* text, const GFXfont* font, uint16_t color) const`

- `void uiEllipsize (const char* text, int maxWidth, char* buffer, int bufferSize) const`

## Key Dependencies

**Local:**
- `SGNode_Base/src/ui/ui_components.h`

**System/External:**
- `<time.h>`
- `<TFT_eSPI.h>`
- `<string.h>`

## Side Effects & Hardware Access

- SD card read
- Touchscreen UI updates
- SPI bus communication

## Change Risks

- **MEDIUM**: UI changes affect user experience

---
*Last modified (hash): 06635495c5c12434af707edcc0300564c792b81aac7252cb1646f26a57818556*

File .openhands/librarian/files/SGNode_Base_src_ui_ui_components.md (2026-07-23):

# SGNode_Base/src/ui/ui_components.h

**Type:** C++ Header
**Hash:** `4882adf86370f4d82d7c90e465c5a249882fa6d9a8c113b8238f0cce2f390636`

## Role

Touchscreen UI components for base station.

## Verified API / Symbols

- Functions: uiDrawTopbar, uiDrawBottomNav, uiNavHitTest, uiCard, uiTile, uiHeroSG, uiDrawSparkline, uiTextCenter, uiTextRight, uiEllipsize

## Key Dependencies

- Arduino.h
- TFT_eSPI.h

## Side Effects

- Touchscreen UI updates

## Tests

- No dedicated automated test identified

## Change Risks

- **MEDIUM**: UI changes affect user experience

---
*Last modified (hash): 4882adf86370f4d82d7c90e465c5a249882fa6d9a8c113b8238f0cce2f390636*

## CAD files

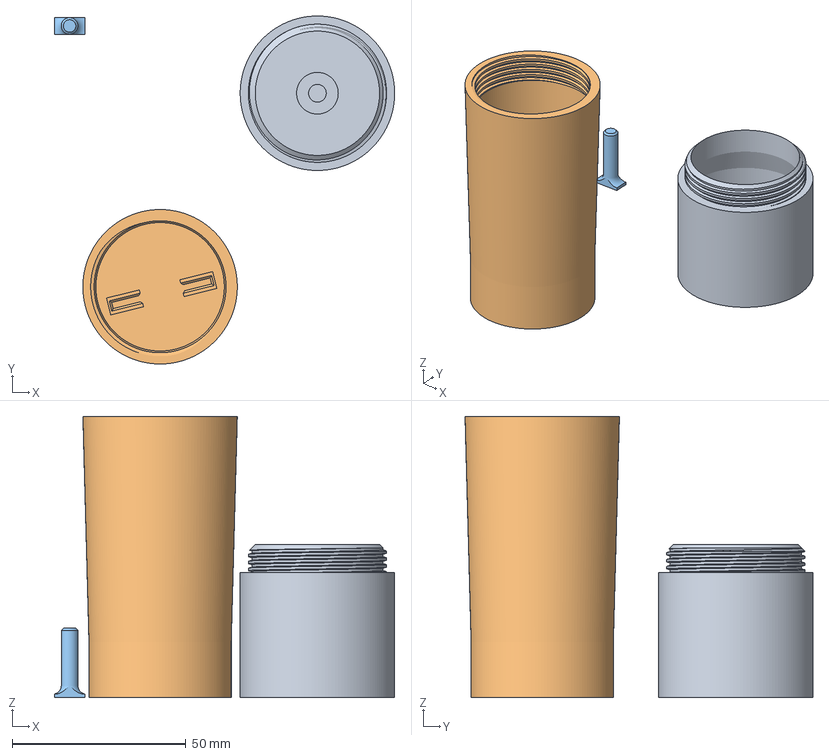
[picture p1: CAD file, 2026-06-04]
Printables/Float.3mf
98.0 x 100.2 x 81.0 mm
Cap.stl
Body.stl
Pin.stl

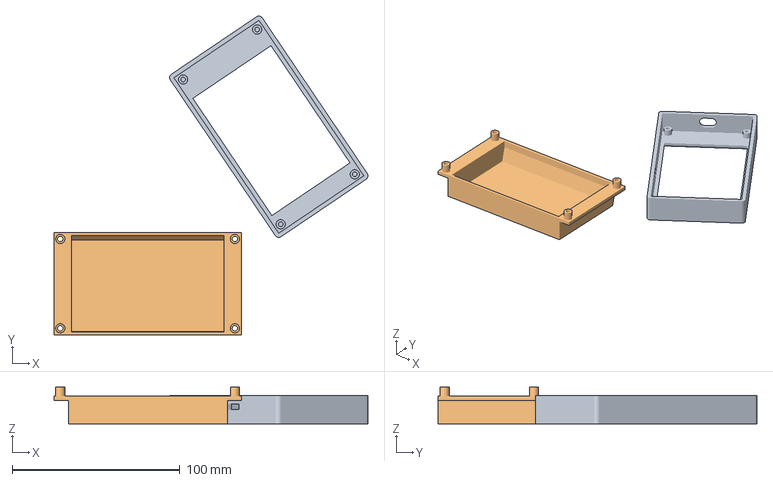
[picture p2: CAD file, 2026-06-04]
Printables/Base.3mf
187.3 x 190.2 x 21.9 mm
PCB - Back-Cover (4).stl
PCB - Front-Cover (2).stl

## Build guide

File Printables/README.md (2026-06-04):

# SGNode 3D Print Files

This folder contains the 3D print files for SGNode:

- `Base.3mf`
- `Float.3mf`

The files are prepared as 3MF projects. Tested print settings are included in the files.

## Base

- Printer: Bambu Lab P1S
- Material: PLA
- File: `Base.3mf`

## Float

- Printer: Bambu Lab P1S
- Material: Creately translucent PETG
- File: `Float.3mf`
- Result: works well with only minor post-processing

## Ballast Weight

A print pause is included in `Float.3mf`. During this pause, insert two M10 washers as ballast weight.

Important:

- Insert both washers fully.
- Make sure they sit flat and do not protrude.
- Continue the print after inserting the washers.

## Post-Processing

After printing, check the mating surfaces and openings. Depending on printer, filament, and calibration, light post-processing may be required.

## Note

The float angle depends on material, print quality, sealing, and the inserted weights. After assembly, test the float in water and calibrate it before use.

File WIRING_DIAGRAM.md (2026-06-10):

# SGNode Wiring Reference

**Current release:** alpha 0.5.0

## Float Unit

### I2C Sensor

```text
BMI160 VCC  -> 3.3V
BMI160 GND  -> GND
BMI160 SDA  -> GPIO26
BMI160 SCL  -> GPIO27
```

The BMP180/GY-68 was removed from the current float hardware. The firmware uses BMI160 chip temperature as a diagnostic value only.

### Battery Measurement

```text
Battery+ -> 51k -> GPIO15 -> 51k -> GND
                    |
                   10 uF
                    |
                   GND
```

GPIO15 is used as ADC input for battery voltage.

### Calibration Switch

```text
GPIO12 -> switch -> GND
```

Closing the switch enters calibration mode. Calibration mode keeps the float awake.

### LEDs

```text
GPIO5   -> built-in/status LED
GPIO16  -> calibration indicator LED
```

## Base Station

The 4.0-inch ESP32-32E display module has display, touch, and SD wiring integrated.

### Internal Reference Pins

```text
Display CS  -> GPIO5
Display DC  -> GPIO4
Display RST -> GPIO2
Touch CS    -> GPIO15
Touch IRQ   -> GPIO27
SD CS       -> GPIO13
SPI MOSI    -> GPIO23
SPI MISO    -> GPIO19
SPI SCK     -> GPIO18
```

### Optional RTC

```text
RTC SDA -> GPIO32
RTC SCL -> GPIO25
RTC VCC -> 3.3V
RTC GND -> GND
```

## Power

```text
Float: 18650 Li-ion in WeMos D32 holder
Base:  5V USB supply, 2A recommended
```

## Quick Checks

- Float BMI160 should be on GPIO26/GPIO27.
- Base station SD card must be FAT32.
- Float calibration switch must be open for normal low-power operation.
- Keep ESP32 antennas away from metal and liquid shielding where possible.

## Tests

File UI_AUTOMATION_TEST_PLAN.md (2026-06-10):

# SGNode Serial UI Automation Test Plan

**Scope:** debug-only UI and firmware regression testing through `SGNODE_UI_TEST_HARNESS`.

**Current release:** alpha 0.5.0

The harness sends serial commands into the native touchscreen UI. Touch simulation enters the same event path as real touch input. The test suite must never commit a destructive user action unless the same final confirmation path a user would press has completed.

## Running

Serial settings:

```text
115200 baud
Newline line ending
```

Basic checks:

```text
help
screen
dump_ui
selftest
run_input_validation_tests
run_sensor_edge_tests
run_state_logic_tests
run_ui_safety_tests
run_batch_restore_tests
run_fallback_log_tests
run_completed_batch_tests
run_manage_brew_ui_tests
run_ui_regression_tests
```

Prefer the smaller focused commands during development because they keep ESP32 loop stack usage low. The full regression command prints one result per test:

```text
OK TEST CalibrationAbortSafety PASS
ERR TEST CancelConfirmation FAIL step=discard_dialog expected=visible actual=missing
```

Then it prints one summary:

```text
ERR ui_regression total=36 passed=28 failed=8 first_failure=InvalidBrixInput:validation
```

## Test Matrix

| # | Test | Method | Expected |
| ---: | --- | --- | --- |
| 1 | Calibration Abort Safety | Soft calibration draft, no save | Existing coefficients unchanged |
| 2 | Calibration Power-Loss Simulation | Partial draft reset | Previous calibration still produces valid SG |
| 3 | Calibration Final Save | Save/reload temporary coefficients, then restore old values | New coefficients reload, old values restored |
| 4 | New Batch Abort Before Confirm | Open wizard, enter partial data, back out | No `profile.json` |
| 5 | New Batch Abort After Partial Draft | Forward/back/cancel flow | No committed batch |
| 6 | New Batch Final Confirm | Create `test_batch` | `profile.json`, `target.json`, and initial `log.csv` exist |
| 7 | Batch Start Gate | Complete wizard, then simulate pre-start packets | Live display may update, CSV rows wait for `Put Float In Brew` |
| 8 | Quick Zero Calibration Gate | New batch starts with level-float action | Calibration ACK path runs before brew-start confirmation |
| 9 | Plug Wizard Toggle | Open Brew Wizard Plug step | `plugControlEnabled` stores selected per-batch mode |
| 10 | Duplicate Batch Name | Existing test batch then new wizard | New batch id is unique |
| 11 | Invalid Brix Input | Calculation/validation probe | Invalid values rejected or flagged |
| 12 | Invalid Batch Size | Validation probe | Invalid volume rejected |
| 13 | Invalid Attenuation | FG bounds probe | No invalid FG |
| 14 | Auto Mode Toggle Consistency | Toggle source fields | Correct `attenuationSource` |
| 15 | Yeast Preset Missing/Corrupt | Missing preset lookup | Fallback preset exists |
| 16 | OG Verification Abort | Pending choice without selection | `effectiveOG` unchanged |
| 17 | OG Verification Recipe | Confirm recipe OG | `effectiveOG == recipeOG` |
| 18 | OG Verification Measured | Confirm measured OG | `effectiveOG == measuredOG` |
| 19 | Sensor Dropout | Mock invalid SG/temp | UI remains responsive, sensor issue visible |
| 20 | Extreme Sensor Values | Mock SG/temp extremes | No NaN/inf/crash |
| 21 | State Machine Spike | Normal drop then SG spike | State does not reset to idle |
| 22 | Stable Gravity Detection | Short/long stability simulation | Not ready early, stable later |
| 23 | Diacetyl Rest Logic | Lager and ale profiles | Lager triggers, ale does not auto-trigger |
| 24 | Reboot During Active Batch | Soft reload from SD | Active profile reloads |
| 24b | Mock Time Isolation | Set mock time, then write via normal CSV logger | CSV epoch uses RTC time, not mock time |
| 24c | Historical Mixed Log Filter | Build log with rows before and after `createdAt` | Loaded/skipped/error counts expose filtered rows |
| 24d | Active Batch Restore Safety | Create older active batch and newer inactive batch | Boot restore must not blindly load highest batch number |
| 24e | Fallback Uses Log Data | No active marker, higher empty batch exists | Select batch with valid post-`createdAt` log data |
| 25 | Manage Brew Delete Geometry | Open Manage Brew with multiple batches | Next/delete touch targets do not overlap |
| 26 | SD Card Missing | Fault-injection placeholder | Must be implemented with SD mock/hardware test |
| 27 | Corrupt profile.json | Fault-injection placeholder | Must be implemented with file mutation/recovery |
| 28 | Corrupt target.json | Fault-injection placeholder | Must be implemented with file mutation/regeneration |
| 29 | Log Append Failure | Fault-injection placeholder | Must be implemented with SD write failure mock |
| 30 | Touch Spam | Rapid next/back taps | No crash/double create |
| 31 | Back Navigation | Enter, forward, back | Values retained |
| 32 | Cancel Confirmation | Press cancel after edits | `Discard changes?` dialog appears |
| 33 | Completed Batch Protection | Completed state lock probe | Completed batch protected from overwrite |
| 34 | Dashboard No Batch | Delete test batch | Dashboard survives no active batch |
| 35 | Long Text Input | Long batch name | Bounded safely |
| 36 | Special Characters | Unsupported chars and safe ASCII | No invalid paths or overflow |
| 37 | Memory/Heap Stability | Repeated create/delete | Heap does not steadily fall |
| 38 | Full End-to-End Auto Mode | Auto batch plus mock SG | ETA/recommendations present |
| 39 | Full End-to-End Manual Mode | Manual profile | `attenuationSource == manual` |

## Remaining Alpha Gaps

Some checks still require fault injection, hardware, or longer runs before they can be considered release gates:

- SD missing fault injection
- Corrupt profile recovery
- Corrupt target regeneration checks
- Log append failure injection
- Strong numeric validation for Brix, batch size, and attenuation
- Plug water/fridge validation with real sensors and relay hardware
- Long-duration batch-start and completed-batch regression runs on the device

These gaps are useful: they define alpha hardening work before a beta label.

## Production Rule

Before production flashing:

```cpp
#define SGNODE_UI_TEST_HARNESS 0
```

The test harness must not ship enabled in a normal build.

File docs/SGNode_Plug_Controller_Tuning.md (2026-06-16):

# SGNode Plug Controller Tuning

This note explains the Plug controller parameters available from SGNode Base.
The goal is practical tuning during water tests and later real fermentation.

## Where The Settings Live

- Open Base `Details`.
- Tap the `PLUG` block 5 times.
- The Plug setup page opens.
- Change a value with `UP`, `DN`, `-`, `+`.
- Press `SAVE`.

Base stores the global controller settings on the SD card:

```text
/data/plug/gov_settings.json
```

These settings are Plug/hardware settings, not batch settings. A test schedule
should only define beer targets and hold times. Controller tuning comes from
`gov_settings.json` and is sent to the Plug with every command.

## Mental Model

Base sends the beer target. The Plug measures:

- `Beer`: sensor in the liquid
- `Air`: sensor in the fridge air

The Plug computes an `Air target`. The compressor relay then follows the air
target with hysteresis.

Simplified:

```text
beer error = beer target - beer actual

air target = beer target
           + P correction
           + I correction
           + D brake
```

Interpretation:

- Beer warmer than target: air target goes colder.
- Beer colder than target: air target goes warmer.
- Beer falling fast: D brake raises air target to reduce undershoot.
- Beer rising fast: D can gently lower air target to reduce overshoot.

The relay itself does not look directly at beer temperature. It cools the air:

```text
relay ON  if air > air target + Air on
relay OFF if air < air target + Air off
```

`Air off` and `Air on` are intentionally above the air target to compensate for
fridge aftercool after the relay switches off.

## First Parameters To Touch

Most tests should start with only these values:

| Menu label | JSON key | Start value | What it does |
| --- | --- | ---: | --- |
| `P` | `kp` | `0.45` | Direct response to beer temperature error. Higher reacts harder. |
| `I Tn` | `integralTnHours` | `0.75h` | Integral speed when near target. Lower means faster correction. |
| `D brake` | `dBrakeHours` | `0.80h` | Brakes fast beer temperature movement. Higher brakes earlier/stronger. |
| `Air off` | `airTurnOffAboveTargetC` | `0.50K` | Relay switches off at air target + this value. Higher reduces undershoot. |
| `Air on` | `airTurnOnAboveTargetC` | `1.10K` | Relay switches on at air target + this value. Higher reduces cycling. |
| `Beer lock` | `beerUndershootLockoutC` | `0.10K` | Blocks cooling when beer is already below target by this amount. |
| `D max` | `maxDOffsetC` | `0.90K` | Maximum D correction. Lower avoids excessive air target jumps. |
| `D warm` | `warmingDFactor` | `0.25` | D strength while beer is warming. Keep much smaller than cooling D. |

For the current 13 L water/fridge setup, based on the stable 9 C hold and the
clean 4 C hold seen on the earlier SD data, use:

```text
P          0.45
I Tn       0.75h
D brake    0.80h
Air off    0.50K
Air on     1.10K
Beer lock  0.10K
D max      0.90K
D warm     0.25
```

## Full Parameter Reference

### P

Direct proportional correction.

- Increase if beer target is missed for a long time and air target looks too timid.
- Decrease if air target moves too aggressively or the relay cycles too hard.
- Good test range: `0.30` to `0.70`.

### I Tn

Integral time constant in hours. Active only near target.

- Lower value: integral corrects faster.
- Higher value: integral corrects slower.
- `0` disables integral action.
- Good test range: `0.5h` to `2.0h`.

Use lower `I Tn` when the hold phase sits consistently too cold or too warm.
Use higher `I Tn` if the air target slowly walks away after a disturbance.

### D brake

Derivative brake based on measured beer rate in K/h.

- Beer falling: D raises air target to reduce cold undershoot.
- Beer rising: D is multiplied by `D warm`, so it brakes warm overshoot gently.
- Good test range: `0.5h` to `1.5h`.

If cooling undershoots below target, increase `D brake` or reduce `D max` less.
If the controller becomes hesitant and never cools hard enough, lower `D brake`.

### Air off

Relay-off threshold relative to air target.

```text
relay OFF if air < air target + Air off
```

Increasing `Air off` turns the compressor off earlier/warmer. This is useful
when the fridge keeps cooling strongly after relay off.

### Air on

Relay-on threshold relative to air target.

```text
relay ON if air > air target + Air on
```

Increasing `Air on` makes the compressor wait longer before restarting.
This reduces short cycling.

Keep `Air on` greater than or equal to `Air off`. A useful gap is `0.4K` to
`0.8K`.

### Min on / Min off

Minimum relay on/off times.

- `Min on`: compressor must stay on at least this long.
- `Min off`: compressor must stay off at least this long.

Current defaults:

```text
Min on   120s
Min off  300s
```

For a real fridge, do not make `Min off` too short.

### I cold band

Integral is active when beer is too cold but close enough to target:

```text
0 <= beer error <= I cold band
```

Beer error is `target - beer`.

Increase if cold undershoot recovery is too slow near target.
Decrease if the integral fights too early during larger ramps.

### I warm band

Integral is active when beer is too warm but close enough to target:

```text
beer is above target by up to I warm band
```

Increase if warm-side steady-state error remains too long.
Decrease if it winds up during cooling ramps.

### I max + / I max -

Limits for integral correction.

- `I max +`: maximum warm air offset from integral.
- `I max -`: maximum cold air offset from integral.

`I max -` is negative. Keep it modest so the controller does not keep pulling
the air target colder after the fridge aftercool is already doing the work.

### I leak

How fast the integral decays when it is outside its active band.

- Higher: old integral memory disappears faster.
- Lower: old correction persists longer.

Good range: `0.5` to `2.0` per hour.

### Cross keep

How much integral remains when the beer error changes sign.

- `0.00`: erase integral at crossing.
- `0.25`: keep 25 percent.
- `1.00`: keep all integral.

Low values reduce overshoot after crossing the target.

### D max

Maximum absolute D correction in K.

If beer rate is noisy, D can cause large air target jumps. `D max` caps that.

Good range: `0.6K` to `1.2K`.

### D warm

Multiplier for D while beer is warming.

Example:

```text
D brake = 0.80h
D warm  = 0.25
effective warming D = 0.20h
```

Keep this weaker than cooling D. Passive warmup is slow; too much warming D can
start cooling too early.

### Beer lock

Compressor lockout when beer is already below target:

```text
cooling blocked if beer < beer target - Beer lock
```

Lower value protects against undershoot earlier.

For the 4 C hold, `0.10K` is more suitable than `0.20K`, because the observed
stable band was already slightly below target.

### Warm rate

Exception for upward target steps. If beer is below target but warming faster
than this rate, the Plug may allow cooling to prevent overshoot.

Keep around `1.0K/h` for now. The observed passive warm ramp was around
`0.3K/h`, so cooling stayed blocked, which was correct.

### Under err / Under air

Strong undershoot recovery.

If beer is colder than target by more than `Under err`, the air target is forced
to at least:

```text
beer target + Under air
```

This is mainly a recovery helper after a large cold overshoot.

### Air min / Air max

Hard clamp for computed air target.

- `Air min`: coldest allowed air target.
- `Air max`: warmest allowed air target.

Defaults are intentionally broad:

```text
Air min  1.0 C
Air max  30.0 C
```

Do not use these as normal tuning knobs unless a hardware limit requires it.

### Target step

Beer target change that resets integral memory.

If the target changes more than this amount, the controller clears integral
state so the old phase does not pollute the next one.

Default `0.25K` is reasonable.

## Tuning Recipes

### Beer sits stable below target

Example: target `4.0 C`, beer pendles between `3.7` and `4.0 C`.

Try in this order:

1. Lower `Beer lock` to `0.10K`.
2. Raise `Air off` by `+0.1K` to `+0.2K`.
3. Raise `Air on` by the same amount or a little more.
4. If still too cold after several cycles, lower `D max` slightly or reduce `D brake`.

### Beer overshoots cold during cooling ramp

Try in this order:

1. Increase `D brake`.
2. Increase `Air off`.
3. Reduce `Beer lock`.
4. If D jumps are too harsh, reduce `D max`.

### Beer never reaches target

Try in this order:

1. Increase `P`.
2. Lower `I Tn` if it is already near target.
3. Lower `Air off` and `Air on` slightly.
4. Raise `D max` if D is clipping too early.

### Relay cycles too often

Try in this order:

1. Increase gap between `Air off` and `Air on`.
2. Increase `Min off`.
3. Slightly lower `P`.

### Warm ramp risks overshoot

Try in this order:

1. Keep `D warm` low, around `0.20` to `0.35`.
2. Keep `Warm rate` around `1.0K/h`.
3. Do not cool during normal passive warmup around `0.3K/h`.

## Suggested Water Test Procedure

Change only one or two parameters per phase.

For every change, note:

```text
timestamp
beer target
beer min/max
air min/max
air target min/max
duty
parameter changes
```

Judge the controller by the last 2 to 3 hours of a hold phase, not by the first
cooling transient. The 9 C and 4 C holds looked stable enough to keep the
current defaults. Further tests should mainly check other fill levels and real
fermentation heat, not chase the current water-test hold behavior.

For the current setup, the most interesting validation windows are:

- 4 C hold after the controller has settled.
- Upward ramp from 4 C to 15 C.
- The next cooling ramp back down to 4 C.

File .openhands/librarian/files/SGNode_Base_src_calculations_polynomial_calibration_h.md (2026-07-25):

# SGNode_Base/src/calculations/polynomial_calibration.h

**Type:** C++ Header
**Hash:** `ce07e40c0542bf44ae815f17addd6c4dff6402b6b49043b11548ab6c0a408a36`

## Overview / Role

Mathematical calculations for brewing metrics

## Verified API & Symbols

### Structs & Classes

- `struct CalibrationCoefficients`
  - `float coeff3`
  - `float coeff2`
  - `float coeff1`
  - `float coeff0`
  - `bool isValid`

- `struct CalibrationPoint`
  - `float tilt`
  - `float gravity`
  - `float temperature`

### Functions

- `void initCalibration (void)`

- `void addCalibrationPoint (float tilt, float gravity, float temperature = 20.0)`

- `void calculatePolynomialCoefficients (void)`

- `void saveCalibrationCoefficients (void)`

- `void calculateGravity (float tilt)`

- `void resetCalibration (void)`

- `void testCalibrationAccuracy (void)`

- `void testPolynomialRange (void)`

- `void isCalibrationValid (void)`

- `void printCalibrationCoefficients (void)`

### Macros

- `#define POLYNOMIAL_CALIBRATION_H #define DEBUG_CALIBRATION 0`

- `#define DBG_PRINT(...) Serial.print(__VA_ARGS__)`

- `#define DBG_PRINTLN(...) Serial.println(__VA_ARGS__)`

- `#define DBG_PRINTF(...) Serial.printf(__VA_ARGS__)`

- `#define DBG_PRINT(...) #define DBG_PRINTLN(...)`

- `#define DBG_PRINTF(...) #endif`

- `#define EEPROM_CALIB_MAGIC 0`

- `#define EEPROM_COEFF3 4`

- `#define EEPROM_COEFF2 8`

- `#define EEPROM_COEFF1 12`

- `#define EEPROM_COEFF0 16`

- `#define EEPROM_CALIB_VERSION 20`

- `#define EEPROM_NORM_OFFSET 21`

- `#define EEPROM_NORM_SCALE 25`

- `#define CALIB_MAGIC 0x43414C49 // "CALI" in hex`

- `#define MAX_CALIB_POINTS 10`

## Key Dependencies

**System/External:**
- `<Arduino.h>`
- `<EEPROM.h>`

## Side Effects & Hardware Access

- EEPROM write (persistent storage)
- EEPROM read
- EEPROM initialization
- EEPROM commit (flush)
- Calibration coefficient computation
- Calibration data persistence
- Serial port initialization
- Serial output

## Change Risks

- **HIGH**: Calibration affects all SG readings

---
*Last modified (hash): ce07e40c0542bf44ae815f17addd6c4dff6402b6b49043b11548ab6c0a408a36*

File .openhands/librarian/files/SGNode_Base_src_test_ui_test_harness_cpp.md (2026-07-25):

# SGNode_Base/src/test/ui_test_harness.cpp

**Type:** C++ Source
**Hash:** `5c73a72cf6b9c3f4bcde458ab10a9f16ece2be25f0d1d13208da0426c63e2ceb`

## Overview / Role

User interface components and rendering

## Verified API & Symbols

### Functions

- `void forceRedrawFlags (void)`

- `void printOK (const char* message) const`

- `void printERR (const char* message) const`

- `void skipSpaces (char* text)`

- `void parseQuoted (char* text, char* out, size_t outSize)`

- `void handleCommand (char* line)`

- `void handleUITestHarness (void)`

## Key Dependencies

**Local:**
- `SGNode_Base/src/test/ui_test_harness.h`

**System/External:**
- `<stdio.h>`
- `<stdlib.h>`
- `<string.h>`

## Side Effects & Hardware Access

- SD card read
- Sensor reading
- Touchscreen UI updates
- Serial output

## Change Risks

- **MEDIUM**: UI changes affect user experience

---
*Last modified (hash): 5c73a72cf6b9c3f4bcde458ab10a9f16ece2be25f0d1d13208da0426c63e2ceb*

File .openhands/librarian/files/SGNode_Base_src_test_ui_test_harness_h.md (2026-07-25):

# SGNode_Base/src/test/ui_test_harness.h

**Type:** C++ Header
**Hash:** `ee973988f2ce2d4d43b19ab139256be40b5f425b5c585e64343cdf746b2ee171`

## Overview / Role

User interface components and rendering

## Verified API & Symbols

### Functions

- `void handleUITestHarness (void)`

### Macros

- `#define UI_TEST_HARNESS_H #include <Arduino.h>`

- `#define SGNODE_UI_TEST_HARNESS 0  // Temporary debug-only harness. Keep disabled for production builds.`

## Key Dependencies

**System/External:**
- `<Arduino.h>`

## Side Effects & Hardware Access

- No significant side effects

## Change Risks

- **MEDIUM**: UI changes affect user experience

---
*Last modified (hash): ee973988f2ce2d4d43b19ab139256be40b5f425b5c585e64343cdf746b2ee171*

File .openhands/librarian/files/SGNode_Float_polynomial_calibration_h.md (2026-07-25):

# SGNode_Float/polynomial_calibration.h

**Type:** C++ Header
**Hash:** `c860828f3335f16a3f4f0f5696c0c8c764af20b02a3d7d745f6d3b03f63c7698`

## Overview / Role

3rd degree polynomial calibration for gravity measurement

## Verified API & Symbols

### Structs & Classes

- `struct CalibrationCoefficients`
  - `float coeff3`
  - `float coeff2`
  - `float coeff1`
  - `float coeff0`
  - `bool isValid`
  - `float norm_min`
  - `float norm_range`

- `struct SensorOffsets`
  - `float offsetX`
  - `float offsetY`
  - `float offsetZ`
  - `bool isValid`

- `struct CalibrationPoint`
  - `float tilt`
  - `float gravity`
  - `float temperature`

### Functions

- `void initCalibration (void)`

- `void addCalibrationPoint (float tilt, float gravity, float temperature = 20.0)`

- `void calculatePolynomialCoefficients (void)`

- `void saveCalibrationCoefficients (void)`

- `void calculateGravity (float tilt)`

- `void resetCalibration (void)`

- `void testCalibrationAccuracy (void)`

- `void isCalibrationValid (void)`

- `void printCalibrationCoefficients (void)`

- `void initSensorOffsets (void)`

- `void calibrateSensorOffset (void)`

- `void loadSensorOffsets (void)`

- `void saveSensorOffsets (void)`

- `void applySensorOffsets (int &ax, int &ay, int &az)`

- `void isSensorOffsetValid (void)`

- `void printSensorOffsets (void)`

### Macros

- `#define POLYNOMIAL_CALIBRATION_H #include <Arduino.h>`

- `#define EEPROM_CALIB_MAGIC 0`

- `#define EEPROM_COEFF3 4`

- `#define EEPROM_COEFF2 8`

- `#define EEPROM_COEFF1 12`

- `#define EEPROM_COEFF0 16`

- `#define EEPROM_CALIB_VERSION 20`

- `#define EEPROM_POLY_DEGREE 21`

- `#define EEPROM_NORM_MIN 22`

- `#define EEPROM_NORM_RANGE 26`

- `#define EEPROM_OFFSET_X 30`

- `#define EEPROM_OFFSET_Y 34`

- `#define EEPROM_OFFSET_Z 38`

- `#define EEPROM_OFFSET_VALID 42`

- `#define EEPROM_OFFSET_MAGIC 46`

- `#define CALIB_MAGIC 0x43414C49 // "CALI" in hex`

- `#define OFFSET_MAGIC 0x4F464654 // "OFFT" in hex`

- `#define MAX_CALIB_POINTS 10`

## Key Dependencies

**System/External:**
- `<Arduino.h>`
- `<EEPROM.h>`

## Side Effects & Hardware Access

- EEPROM write (persistent storage)
- EEPROM read
- EEPROM initialization
- EEPROM commit (flush)
- Sensor reading
- Calibration coefficient computation
- Calibration data persistence
- Execution delay
- Serial port initialization
- Serial output

## Change Risks

- **HIGH**: Calibration affects all SG readings

---
*Last modified (hash): c860828f3335f16a3f4f0f5696c0c8c764af20b02a3d7d745f6d3b03f63c7698*

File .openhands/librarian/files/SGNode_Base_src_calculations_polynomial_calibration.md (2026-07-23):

# SGNode_Base/src/calculations/polynomial_calibration.h

**Type:** C++ Header
**Hash:** `ce07e40c0542bf44ae815f17addd6c4dff6402b6b49043b11548ab6c0a408a36`

## Role

Gravity calibration system (EEPROM-stored polynomial coefficients).

## Verified API / Symbols

- Structs: CalibrationCoefficients, CalibrationPoint

- Functions: initCalibration

## Key Dependencies

- Arduino.h
- EEPROM.h (for storing coefficients)

## Side Effects

- EEPROM read
- Calibration coefficient computation

## Tests

- No dedicated automated test identified

## Change Risks

- **HIGH**: Calibration affects all SG readings

---
*Last modified (hash): ce07e40c0542bf44ae815f17addd6c4dff6402b6b49043b11548ab6c0a408a36*

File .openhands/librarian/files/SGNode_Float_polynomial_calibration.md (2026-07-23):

# SGNode_Float/polynomial_calibration.h

**Type:** C++ Header
**Hash:** `c860828f3335f16a3f4f0f5696c0c8c764af20b02a3d7d745f6d3b03f63c7698`

## Role

Gravity calibration system (EEPROM-stored polynomial coefficients).

## Verified API / Symbols

- Structs: CalibrationCoefficients, SensorOffsets, CalibrationPoint

- Functions: initCalibration, addCalibrationPoint

## Key Dependencies

- Arduino.h
- EEPROM.h (for storing coefficients)

## Side Effects

- EEPROM read
- Sensor reading
- Calibration coefficient computation

## Tests

- No dedicated automated test identified

## Change Risks

- **HIGH**: Calibration affects all SG readings

---
*Last modified (hash): c860828f3335f16a3f4f0f5696c0c8c764af20b02a3d7d745f6d3b03f63c7698*

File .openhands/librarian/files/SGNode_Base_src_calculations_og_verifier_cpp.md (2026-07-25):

# SGNode_Base/src/calculations/og_verifier.cpp

**Type:** C++ Source
**Hash:** `0afec698748e82e2cec90c1a277b31e3fc56c10c3e2ed2a3715a84d90f9dc3aa`

## Overview / Role

Mathematical calculations for brewing metrics

## Verified API & Symbols

### Functions

- `void OGVerifier (void)`

- `void reset (void)`

- `void addReading (float sg)`

- `void exceedsThreshold (float difference)`

## Key Dependencies

**Local:**
- `SGNode_Base/src/calculations/og_verifier.h`

## Side Effects & Hardware Access

- No significant side effects

## Change Risks

- **MEDIUM**: Calculation changes affect data accuracy

---
*Last modified (hash): 0afec698748e82e2cec90c1a277b31e3fc56c10c3e2ed2a3715a84d90f9dc3aa*

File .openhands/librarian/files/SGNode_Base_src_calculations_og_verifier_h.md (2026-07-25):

# SGNode_Base/src/calculations/og_verifier.h

**Type:** C++ Header
**Hash:** `7cd8842a7dc2c6c17055c48ca72b5647b7033b5a860d16baebd26bbf43b53515`

## Overview / Role

Mathematical calculations for brewing metrics

## Verified API & Symbols

### Structs & Classes

- `struct OGVerificationResult`
  - `bool ready`
  - `bool needsUserChoice`
  - `float measuredOG`
  - `float ogDifference`

- `class OGVerifier`
  - OGVerifie r (void)
  - void reset (void)
  - OGVerificationResult addReading (float sg)
  - bool exceedsThreshold (float difference) static

### Macros

- `#define OG_VERIFIER_H struct OGVerificationResult {`

## Key Dependencies

- No external dependencies

## Side Effects & Hardware Access

- No significant side effects

## Change Risks

- **MEDIUM**: Calculation changes affect data accuracy

---
*Last modified (hash): 7cd8842a7dc2c6c17055c48ca72b5647b7033b5a860d16baebd26bbf43b53515*

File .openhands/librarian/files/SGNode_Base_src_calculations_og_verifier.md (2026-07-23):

# SGNode_Base/src/calculations/og_verifier.h

**Type:** C++ Header
**Hash:** `7cd8842a7dc2c6c17055c48ca72b5647b7033b5a860d16baebd26bbf43b53515`

## Role

Header file with declarations.

## Verified API / Symbols

- Structs: OGVerificationResult
- Classes: OGVerifier

- Functions: reset, exceedsThreshold

## Key Dependencies

- No external dependencies

## Side Effects

- No significant side effects

## Tests

- No dedicated automated test identified

## Change Risks

- **MEDIUM**: Calculation changes affect data accuracy

---
*Last modified (hash): 7cd8842a7dc2c6c17055c48ca72b5647b7033b5a860d16baebd26bbf43b53515*

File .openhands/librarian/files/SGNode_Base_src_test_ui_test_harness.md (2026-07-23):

# SGNode_Base/src/test/ui_test_harness.h

**Type:** C++ Header
**Hash:** `ee973988f2ce2d4d43b19ab139256be40b5f425b5c585e64343cdf746b2ee171`

## Role

Touchscreen UI components for base station.

## Verified API / Symbols

- Functions: handleUITestHarness

## Key Dependencies

- Arduino.h
- TFT_eSPI.h

## Side Effects

- No significant side effects

## Tests

- Unit test infrastructure for UI

## Change Risks

- **MEDIUM**: UI changes affect user experience

---
*Last modified (hash): ee973988f2ce2d4d43b19ab139256be40b5f425b5c585e64343cdf746b2ee171*

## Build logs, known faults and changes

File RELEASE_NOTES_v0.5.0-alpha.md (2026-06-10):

# SGNode alpha 0.5.0 Release Notes

**Date:** 2026-06-10  
**Status:** Alpha test build  
**Focus:** Batch-start safety, first real-batch learnings, and SGNode Plug alpha groundwork

## Summary

alpha 0.5.0 keeps SGNode in alpha. Float/Base have completed a first real fermentation run, but SGNode Plug temperature control still needs water/fridge validation before a beta label is justified.

## Added

- Batch-start zero calibration using the normal Float ACK/downlink path.
- Required `Put Float In Brew` action before new-batch logging and fermentation analysis start.
- SGNode Plug alpha firmware for Gosund SP1 / ESP8285.
- Shared Base/Plug ESP-NOW command and status protocol.
- Base-side Plug MAC learning, status handling, command sender, UI diagnostics, and CSV fields.
- Brew Wizard Plug Auto Mode toggle.

## Changed

- Base boot screen and serial startup text now show `alpha 0.5.0`.
- New-batch `createdAt`, `log.csv`, and target curves start from `Put Float In Brew` confirmation.
- Float packets received before `Put Float In Brew` update Live view but are not written to the active CSV.
- Float temperature now uses BMI160 chip temperature because the BMP180/GY-68 was removed from the reference hardware.
- Manage Brew delete uses the batch directory name and removes the whole batch directory.
- Plug test sketches are local-only and ignored by Git.

## Fixed

- Manage Brew delete and next buttons overlapping on the 4-inch display.
- Zero-calibration debug ACK messages sticking in the Dashboard after success.
- Quick zero calibration rejecting the real mounted sensor because of a too-narrow raw acceleration magnitude window.

## Hardware Notes

- BMP180/GY-68 removed from the Float; BMI160 chip temperature is diagnostic only.
- USB-UART leakage was reduced by isolating pin 8 on the tested CP2302/USB-UART chip.
- ME6220 regulator swap was tested but did not provide enough benefit to recommend as a priority modification.
- Reference Float deep sleep current after practical changes is about `0.95 mA`.

## Known Risks

- SGNode Plug remains alpha until water/fridge tests validate controller stability, logging, compressor timing, and fallback behavior.
- Float BMI160 temperature is not representative beer temperature.
- Long-duration runs are still needed to tune phase thresholds, ETA behavior, and Plug PI parameters.

## Recommended Test Pass

1. Create a new batch and verify `Level Float` then `Put Float In Brew`.
2. Confirm packets before `Put Float In Brew` are live-only and not appended to `log.csv`.
3. Confirm `log.csv` starts at the real batch confirmation time.
4. Test Manage Brew continue, copy, and delete with several batches.
5. Run SGNode Plug with water in the fridge before enabling it on a real fermentation.

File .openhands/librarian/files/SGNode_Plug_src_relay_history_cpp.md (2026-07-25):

# SGNode_Plug/src/relay_history.cpp

**Type:** C++ Source
**Hash:** `9c1ffb563f513bb7c09226bc05075cb936f5031fef721ebf19f9db7bed91f8bd`

## Overview / Role

Core functionality module

## Verified API & Symbols

### Functions

- `void recordSecond (bool relayOn)`

- `void recordMinute (bool relayOn)`

- `void startReplay (void)`

- `void nextReplayMinute (void)`

## Key Dependencies

**Local:**
- `SGNode_Plug/src/relay_history.h`

## Side Effects & Hardware Access

- No significant side effects

## Change Risks

- **HIGH**: Relay control affects hardware

---
*Last modified (hash): 9c1ffb563f513bb7c09226bc05075cb936f5031fef721ebf19f9db7bed91f8bd*

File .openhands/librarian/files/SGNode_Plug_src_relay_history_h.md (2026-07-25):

# SGNode_Plug/src/relay_history.h

**Type:** C++ Header
**Hash:** `8673e99bd10d2457277e3c16df54b18294b816088c090e9bc81244ed8f01a6b0`

## Overview / Role

Core functionality module

## Verified API & Symbols

### Structs & Classes

- `class RelayDutyWindow`
  - void recordSecond (bool relayOn)
  - float dutyPercent (void)
  - uint16_t sampleCount (void)

- `class CompressorPattern`
  - void recordMinute (bool relayOn)
  - bool complete (void)
  - void startReplay (void)
  - bool nextReplayMinute (void)
  - uint16_t replayPosition (void)

## Key Dependencies

**System/External:**
- `<Arduino.h>`

## Side Effects & Hardware Access

- No significant side effects

## Change Risks

- **HIGH**: Relay control affects hardware

---
*Last modified (hash): 8673e99bd10d2457277e3c16df54b18294b816088c090e9bc81244ed8f01a6b0*

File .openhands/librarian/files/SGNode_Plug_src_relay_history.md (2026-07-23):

# SGNode_Plug/src/relay_history.h

**Type:** C++ Header
**Hash:** `8673e99bd10d2457277e3c16df54b18294b816088c090e9bc81244ed8f01a6b0`

## Role

Relay duty cycle tracking and compressor pattern generation.

## Verified API / Symbols

- Classes: RelayDutyWindow, CompressorPattern

- Functions: recordSecond, dutyPercent, sampleCount, recordMinute, complete, startReplay, nextReplayMinute, replayPosition

## Key Dependencies

- Arduino.h

## Side Effects

- No significant side effects

## Tests

- No dedicated automated test identified

## Change Risks

- **HIGH**: Relay control affects hardware

---
*Last modified (hash): 8673e99bd10d2457277e3c16df54b18294b816088c090e9bc81244ed8f01a6b0*

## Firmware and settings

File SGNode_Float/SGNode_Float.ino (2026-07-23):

/*
 * Fermentation Monitor - Float Unit (Sensor)
 * Measures tilt via BMI160 IMU and transmits via ESP-NOW
 * Battery-powered with deep sleep for power efficiency
 * 
 * REQUIRED LIBRARIES (install via Arduino Library Manager):
 * - EmotiBit BMI160 (by Connected Future Labs) - Install from:
 *   https://github.com/EmotiBit/EmotiBit_BMI160
 *   Download as ZIP and install via Sketch -> Include Library -> Add .ZIP Library
 * - Wire (built-in)
 * - EEPROM (built-in)
 */

#include <WiFi.h>
#include <esp_now.h>
#include <WebServer.h>
#include <Update.h>
#include <Wire.h>
#include <BMI160Gen.h>
#include "polynomial_calibration.h"
#include "../SGNode_Shared/sg_protocol.h"
#include "../SGNode_Shared/sg_logo_png.h"

// I2C pins for BMI160
#define I2C_SDA 26
#define I2C_SCL 27

// System configuration
#define MEASUREMENT_INTERVAL 600  // seconds (configurable 60-600)
#define SAMPLE_COUNT 5            // samples per measurement (reduced for power efficiency)
#define MAX_RETRIES 1             // transmission retry attempts
#define MAX_INIT_RETRIES 3        // sensor initialization retry attempts
#define BATTERY_PIN 15            // Battery voltage monitoring (GPIO15 - ADC1_CH3)
#define CALIBRATION_SWITCH_PIN 12  // Physical switch for calibration mode (pull-down)
#define ACK_PACKET_TYPE 0xA5
#define RETRY_BUFFER_SIZE 8
#define ACK_WAIT_MS 400
#ifndef SGNODE_FLOAT_TEST_HARNESS
#define SGNODE_FLOAT_TEST_HARNESS 0
#endif
#ifndef SGNODE_FLOAT_SERIAL_DIAG
#define SGNODE_FLOAT_SERIAL_DIAG 0
#endif

// LED indicators (WeMos D32)
#define LED_BUILTIN 16           // Built-in LED - blinks during calibration mode

// ESP-NOW configuration
#define ESPNOW_CHANNEL 1

// Base station MAC address (update with actual address)
uint8_t baseStationMac[] = {0xA4, 0xF0, 0x0F, 0x68, 0x22, 0x00};

payload_t sensorData;

struct StoredPayload {
  bool valid;
  payload_t payload;
};

RTC_DATA_ATTR StoredPayload retryBuffer[RETRY_BUFFER_SIZE];
RTC_DATA_ATTR uint8_t retryWriteIndex = 0;
RTC_DATA_ATTR uint16_t lastAckedSeq = 0;
RTC_DATA_ATTR uint16_t rtcSequenceCounter = 0;
volatile bool ackReceived = false;
volatile uint16_t receivedAckSeq = 0;
RTC_DATA_ATTR uint8_t rtcPendingPayloadFlags = 0;
RTC_DATA_ATTR uint8_t rtcLastAckCommandId = 0;
volatile bool queuedZeroCalCommand = false;
volatile uint8_t queuedZeroCalCommandId = 0;
bool zeroCalProcessedThisWake = false;
#if SGNODE_FLOAT_TEST_HARNESS
bool harnessNoSleep = true;
bool harnessPauseStateMachine = true;
bool harnessMockEnabled = false;
bool harnessRxDebug = false;
uint32_t harnessLastIdlePrint = 0;
float harnessMockAngle = 50.0f;
float harnessMockTemp = 20.0f;
float harnessMockBattery = 4.0f;
float harnessMockSG = 1.000f;
char harnessCommandBuffer[128];
size_t harnessCommandLength = 0;
#endif

// BMI160 instance provided by EmotiBit_BMI160 library
// No need to declare - library provides global BMI160 instance

// Calibration system variables (actual definitions)
CalibrationCoefficients calibCoeffs;
CalibrationPoint calibPoints[MAX_CALIB_POINTS];
int numCalibPoints = 0;

// Sensor offset calibration variables
SensorOffsets sensorOffsets;

// Global variables for filtering and tracking
uint16_t sequence_counter = 0;
uint32_t boot_time = 0;
float ema_temp = 20.0;  // Initial temperature for EMA
const float EMA_ALPHA = 0.2;  // EMA alpha between 0.1-0.3
bool debug_mode = false;  // Debug mode enabled by calibration switch
float cachedBatteryVoltage = 0.0;  // Battery voltage read before WiFi

// State machine states
enum State {
  INIT,
  MEASURE,
  COMPUTE,
  SEND,
  SLEEP
};

// Calibration states
enum CalibState {
  CALIB_IDLE,
  CALIB_MEASURING,
  CALIB_WAITING_COMMAND
};

State currentState = INIT;
CalibState calibState = CALIB_IDLE;

// Calibration mode
bool calibrationMode = false;
uint8_t pendingRequestId = 0;
bool calibrationInProgress = false;

// Push button state tracking
bool lastButtonState = HIGH;
unsigned long lastButtonDebounceTime = 0;
const unsigned long DEBOUNCE_DELAY = 50; // 50ms debounce

// Calibration timeout system
unsigned long lastCalibrationActivity = 0;
const unsigned long CALIBRATION_TIMEOUT = 900000; // 15 minutes in milliseconds
const unsigned long CALIBRATION_NO_COMM_TIMEOUT = 60000; // 1 minute timeout for no communication

// LED blinking for calibration mode
unsigned long lastLedToggle = 0;
const unsigned long LED_BLINK_INTERVAL = 500; // 500ms blink interval
bool ledState = false;
const unsigned long OTA_LONG_PRESS_MS = 5000UL;
const unsigned long OTA_TIMEOUT_MS = 20UL * 60UL * 1000UL;
WebServer floatOtaServer(80);
bool floatOtaActive = false;
bool floatOtaUploadInProgress = false;
unsigned long floatOtaStartedMs = 0;
unsigned long floatOtaButtonPressMs = 0;
bool floatOtaButtonWasPressed = false;
char floatOtaSsid[32] = "";

// Rate limiting for calibration responses
unsigned long lastCalibrationResponse = 0;
const unsigned long CALIBRATION_RESPONSE_INTERVAL = 2000; // 2 seconds between responses
bool calibrationResponsePending = false;

struct PendingStableCalibrationPoint {
  bool active;
  float targetSG;
  uint8_t requestId;
  uint8_t pointNumber;
  unsigned long startedMs;
  unsigned long lastSampleMs;
  int sampleCount;
  float firstAngle;
  float firstTemp;
  float firstSG;
  float lastAngle;
  float lastTemp;
  float lastSG;
  float sumAngle;
  float sumTemp;
};

PendingStableCalibrationPoint pendingStablePoint = {};

struct PendingStableOffsetCalibration {
  bool active;
  uint8_t requestId;
  unsigned long startedMs;
  unsigned long lastSampleMs;
  int sampleCount;
  float firstX;
  float firstY;
  float firstZ;
  float lastX;
  float lastY;
  float lastZ;
  float firstTemp;
  float lastTemp;
  float previousTempDrift;
  unsigned long previousTempDriftMs;
  float peakTempDrift;
  float sumX;
  float sumY;
  float sumZ;
  float sumTemp;
  int minX;
  int minY;
  int minZ;
  int maxX;
  int maxY;
  int maxZ;
};

PendingStableOffsetCalibration pendingStableOffset = {};

// Function prototypes
void initIMU();
void initTemperatureSensor();
void initESPNow();
void configureUnusedGPIOs();
void suspendBMI160();
void ensureDebugSerial();
bool detectOtaLongPressAtBoot(bool switchPressed);
void startFloatOtaMode();
void handleFloatOtaMode();
void stopFloatOtaAndReboot();
void sendFloatOtaActiveStatus();
float measureTilt();
float measureImuTemperature();
float measureTemperature();
float calculateDensity(float angle, float temperature);
float getBatteryVoltage();
void computeSensorData();
void transmitData();
void onDataAck(const uint8_t *mac, const uint8_t *incomingData, int len);
void storePayloadForRetry(const payload_t& payload);
void markAcked(uint16_t sequence_id);
void sendRetryPayloads(bool includeCurrent = false);
bool sendPayloadWithAck(payload_t* payload, bool waitForAck);
void enterDeepSleep();
void onCalibrationCommand(const uint8_t *mac, const uint8_t *incomingData, int len);
void recordCalibrationPoint(float target_sg, uint8_t request_id, uint8_t point_number);
void startStableOffsetCalibration(uint8_t request_id);
void handlePendingStableOffsetCalibration();
void handlePendingStableCalibrationPoint();
bool runQuickZeroCalibration();
bool processQueuedZeroCalibrationCommand();
bool attachPendingFlagsToPayload(payload_t* payload, bool refreshMeasurement);
bool sendPendingZeroCalibrationResult();
void sendCalibrationResponse(float angle, float target_sg, uint8_t request_id, const char* message);
void sendCalibrationStatus(float etaSeconds, float tempDriftPerMin, uint8_t request_id, const char* message);
void sendCalibrationCoefficients(uint8_t request_id);
uint16_t crc16(const uint8_t* data, size_t length);
float ema(float prev, float x, float alpha);
#if SGNODE_FLOAT_TEST_HARNESS
void handleFloatTestHarness();
bool processFloatHarnessCommand(char* line);
int retryBufferCount();
void printFloatHarnessOK(const char* message);
void printFloatHarnessERR(const char* message);
#endif

void setup() {
  // Configure unused GPIOs FIRST to avoid conflicts
  configureUnusedGPIOs();
  
  // Configure pins (after unused GPIOs are set)
  pinMode(BATTERY_PIN, INPUT);
  analogSetPinAttenuation(BATTERY_PIN, ADC_11db);  // Pin 15 is ADC1_CH3 - can use attenuation
  
  // Configure ADC for higher accuracy battery measurements
  analogReadResolution(12);  // Use 12-bit resolution (0-4095)
  // ESP32 Arduino doesn't have analogSetCycles/analogSetSamples functions
  // We'll use our own averaging in the measurement function
  pinMode(CALIBRATION_SWITCH_PIN, INPUT_PULLUP);
  pinMode(LED_BUILTIN, OUTPUT);
  
  // Initialize LED
  digitalWrite(LED_BUILTIN, LOW);
  
  // Check wake-up reason to detect calibration switch press during deepsleep
  esp_sleep_wakeup_cause_t wakeup_reason = esp_sleep_get_wakeup_cause();
  bool calibrationWakeup = false;
  
  if (wakeup_reason == ESP_SLEEP_WAKEUP_EXT0) {
    // Woke up from deepsleep due to external interrupt (calibration switch)
    calibrationWakeup = true;
    if (debug_mode) Serial.println("Woke up from deepsleep - calibration switch detected");
  }
  
  // Read battery voltage BEFORE WiFi is enabled (no interference)
  cachedBatteryVoltage = getBatteryVoltage();
  if (debug_mode) Serial.printf("Initial battery voltage: %.2fV\n", cachedBatteryVoltage);
  
  // Initialize push button state
  lastButtonState = digitalRead(CALIBRATION_SWITCH_PIN);
  
  // Check calibration switch state at boot (before deepsleep)
  bool switchPressed = (digitalRead(CALIBRATION_SWITCH_PIN) == LOW);

  if (detectOtaLongPressAtBoot(switchPressed)) {
    startFloatOtaMode();
    return;
  }
  
  // Activate calibration mode if switch is pressed OR woke up from calibration interrupt
  if (switchPressed || calibrationWakeup) {
    calibrationMode = true;
  } else {
    calibrationMode = false;
  }
  
  debug_mode = calibrationMode;  // Debug mode follows calibration mode
  
  // Start Serial in debug/calibration mode or when diagnostics are compiled in.
  if (debug_mode || SGNODE_FLOAT_TEST_HARNESS || SGNODE_FLOAT_SERIAL_DIAG) {
    Serial.begin(115200);
    delay(100);  // Wait for Serial to initialize

    if (SGNODE_FLOAT_SERIAL_DIAG) {
      Serial.printf("DIAG boot calib=%d switch=%d wake=%d state=%d\n",
                    calibrationMode ? 1 : 0, switchPressed ? 1 : 0,
                    calibrationWakeup ? 1 : 0, (int)currentState);
    }

    if (debug_mode) {
      Serial.println("=== CALIBRATION MODE ACTIVATED AT BOOT ===");
      if (switchPressed) {
        Serial.println("Switch pressed at boot");
      } else {
        Serial.println("Woke up from calibration interrupt");
      }

      Serial.printf("Base Station MAC: %02X:%02X:%02X:%02X:%02X:%02X\n",
                    baseStationMac[0], baseStationMac[1], baseStationMac[2],
                    baseStationMac[3], baseStationMac[4], baseStationMac[5]);
    }
  }
  
  if (calibrationMode) {
    lastCalibrationActivity = millis();
    
    // IMPORTANT: Send calibration trigger after ESP-NOW is initialized
    // This will be called in the state machine after initESPNow()
  }
  
  // Disable Bluetooth
  btStop();
  delay(50);
  
  // Initialize calibration system
  initCalibration();
  
  // Initialize sensor offset system
  initSensorOffsets();

  #if SGNODE_FLOAT_TEST_HARNESS
  Serial.println("OK float_harness_boot continuing_to_imu_init");
  #endif
  
  // Configure I2C with pull-ups
  pinMode(I2C_SDA, INPUT_PULLUP);
  pinMode(I2C_SCL, INPUT_PULLUP);
  Wire.begin(I2C_SDA, I2C_SCL);
  Wire.setClock(100000); // 100 kHz I2C
  
  // Check I2C bus is working
  Wire.beginTransmission(0x69); // BMI160 actual address (found by scanner)
  if (Wire.endTransmission() != 0) {
    if (debug_mode) Serial.println("I2C bus check failed - no device detected");
  } else {
    if (debug_mode) Serial.println("I2C bus initialized successfully");
  }
  
  // Record boot time
  boot_time = millis() / 1000;
  
  if (calibrationMode) {
    if (debug_mode) Serial.println("Button activated - Deep sleep disabled");
        lastCalibrationActivity = millis(); // Initialize timeout counter
    if (isCalibrationValid()) {
      if (debug_mode) Serial.println("Valid calibration found from EEPROM");
      if (debug_mode) printCalibrationCoefficients();
    } else {
      if (debug_mode) Serial.println("No valid calibration - ready for new calibration");
    }
  }
  
  if (debug_mode) Serial.println("Hardware initialized");

  #if SGNODE_FLOAT_TEST_HARNESS
  initIMU();
  Serial.println("OK float_harness_ready paused=1 imu=1");
  #endif
}

void loop() {
  if (floatOtaActive) {
    handleFloatOtaMode();
    delay(5);
    return;
  }

  #if SGNODE_FLOAT_TEST_HARNESS
  handleFloatTestHarness();
  if (harnessPauseStateMachine) {
    delay(10);
    return;
  }
  #endif
  
  // Ensure debug_mode follows calibration mode
  debug_mode = calibrationMode;

  #if SGNODE_FLOAT_SERIAL_DIAG
  static unsigned long lastDiagPrint = 0;
  if (millis() - lastDiagPrint > 5000UL) {
    lastDiagPrint = millis();
    Serial.printf("DIAG loop calib=%d state=%d button=%d pendingOffset=%d pendingPoint=%d\n",
                  calibrationMode ? 1 : 0, (int)currentState,
                  digitalRead(CALIBRATION_SWITCH_PIN),
                  pendingStableOffset.active ? 1 : 0,
                  pendingStablePoint.active ? 1 : 0);
  }
  #endif
  
  // Handle push button detection with debouncing
  bool currentButtonState = digitalRead(CALIBRATION_SWITCH_PIN);
  
  // Debug button state (remove after testing) - only in non-calibration mode
  static unsigned long lastDebugPrint = 0;
  if (!calibrationMode && debug_mode && millis() - lastDebugPrint > 1000) {
    Serial.printf("Button state: %d (pin %d)\n", currentButtonState, CALIBRATION_SWITCH_PIN);
    lastDebugPrint = millis();
  }
  
  if (currentButtonState != lastButtonState) {
    lastButtonDebounceTime = millis();
  }
  
  // Check if button state is stable (debounced)
  if ((millis() - lastButtonDebounceTime) > DEBOUNCE_DELAY) {
    static bool stableButtonState = HIGH;
    if (currentButtonState != stableButtonState) {
      stableButtonState = currentButtonState;
      if (stableButtonState == LOW) {
        // Button pressed (falling edge detected)
        if (debug_mode) Serial.println("Button press detected!");
        toggleCalibrationMode();
      }
    }
  }
  
  lastButtonState = currentButtonState;
  
  // Handle calibration timeout
  if (calibrationMode && (millis() - lastCalibrationActivity) > CALIBRATION_TIMEOUT) {
    if (debug_mode) Serial.println("Calibration timeout - exiting calibration mode");
    exitCalibrationMode();
  }
  
  // Handle no-communication timeout (exit if no base station communication for 1 minute)
  if (calibrationMode && (millis() - lastCalibrationActivity) > CALIBRATION_NO_COMM_TIMEOUT) {
    static bool noCommWarningShown = false;
    if (!noCommWarningShown) {
      if (debug_mode) Serial.println("Warning: No base station communication detected");
      if (debug_mode) Serial.println("Press button again to exit calibration mode");
      noCommWarningShown = true;
    }
  }
  
  // Handle LED blinking during calibration mode
  if (calibrationMode) {
    if ((millis() - lastLedToggle) > LED_BLINK_INTERVAL) {
      ledState = !ledState;
      digitalWrite(LED_BUILTIN, ledState ? HIGH : LOW);
      lastLedToggle = millis();
    }
  } else {
    digitalWrite(LED_BUILTIN, LOW); // Ensure LED is off when not in calibration mode
  }
  
  // Normal operation
  switch (currentState) {
    case INIT:
      if (debug_mode) Serial.println("State: INIT");
      delay(100);   // Short stabilization delay after wake
      initIMU();
      initTemperatureSensor();
      // WiFi initialization moved to SEND state for power savings
      
      // Send calibration trigger if in calibration mode and ESP-NOW is ready
      if (calibrationMode) {
        initESPNow();  // Only init WiFi in calibration mode
        static bool calibrationTriggerSent = false;
        if (!calibrationTriggerSent) {
          sendCalibrationTrigger();
          calibrationTriggerSent = true;
          if (debug_mode) Serial.println("Calibration trigger sent after ESP-NOW initialization");
        }
      }
      
      currentState = MEASURE;
      break;
      
    case MEASURE:
      sensorData.angle = measureTilt();
      currentState = COMPUTE;
      break;
      
    case COMPUTE:
      computeSensorData();
      currentState = SEND;
      break;
      
    case SEND:
      // Initialize WiFi only when needed for transmission (power savings)
      if (!calibrationMode) {
        initESPNow();  // Initialize WiFi/ESP-NOW only for transmission
        if (debug_mode) Serial.println("Transmitting normal sensor data");
        transmitData();
        currentState = SLEEP;
      } else {
        // In calibration mode, check for pending responses and continue measuring
        handlePendingStableOffsetCalibration();

        static unsigned long lastCalibMsg = 0;
        if (millis() - lastCalibMsg > 10000) { // Only show message every 10 seconds
          if (debug_mode) Serial.println("Calibration mode active - waiting for commands...");
          lastCalibMsg = millis();
        }
        if (calibrationResponsePending) {
          // Try to send pending calibration response
          if (millis() - lastCalibrationResponse >= CALIBRATION_RESPONSE_INTERVAL) {
            // Reset rate limiting to allow pending response
            lastCalibrationResponse = 0;
            calibrationResponsePending = false;
            if (debug_mode) Serial.println("Retrying pending calibration response");
          }
        }
        currentState = MEASURE;
        delay(1000); // Slower cycle in calibration mode
      }
      break;
      
    case SLEEP:
      if (debug_mode) Serial.println("State: SLEEP");
      enterDeepSleep();
      break;
  }
  
  delay(10);
}

bool detectOtaLongPressAtBoot(bool switchPressed) {
  if (!switchPressed) return false;
  unsigned long startMs = millis();
  while (digitalRead(CALIBRATION_SWITCH_PIN) == LOW) {
    if (millis() - lastLedToggle > 200UL) {
      ledState = !ledState;
      digitalWrite(LED_BUILTIN, ledState ? HIGH : LOW);
      lastLedToggle = millis();
    }
    if (millis() - startMs >= OTA_LONG_PRESS_MS) {
      digitalWrite(LED_BUILTIN, LOW);
      return true;
    }
    delay(10);
  }
  digitalWrite(LED_BUILTIN, LOW);
  return false;
}

String floatOtaDiagHtml() {
  String html;
  html.reserve(1200);
  uint32_t elapsed = (millis() - floatOtaStartedMs) / 1000UL;
  uint32_t remain = elapsed < (OTA_TIMEOUT_MS / 1000UL) ? (OTA_TIMEOUT_MS / 1000UL) - elapsed : 0UL;
  html += "<pre>";
  html += "Firmware: SGNode Float ";
  html += __DATE__;
  html += " ";
  html += __TIME__;
  html += "\nChip: ";
  html += String((uint32_t)ESP.getEfuseMac(), HEX);
  html += "\nMAC: ";
  html += WiFi.macAddress();
  html += "\nFlash: ";
  html += String(ESP.getFlashChipSize());
  html += "\nSketch: ";
  html += String(ESP.getSketchSize());
  html += "\nFree sketch: ";
  html += String(ESP.getFreeSketchSpace());
  html += "\nFree heap: ";
  html += String(ESP.getFreeHeap());
  html += "\nUptime: ";
  html += String(millis() / 1000UL);
  html += " s\nReset: ";
  html += String((int)esp_reset_reason());
  html += "\nAP SSID: ";
  html += floatOtaSsid;
  html += "\nAP IP: ";
  html += WiFi.softAPIP().toString();
  html += "\nOTA rest: ";
  html += String(remain);
  html += " s\nBattery: ";
  html += String(cachedBatteryVoltage, 2);
  html += " V\nSeq: ";
  html += String(rtcSequenceCounter);
  html += "\nCalibration: ";
  html += calibrationMode ? "on" : "off";
  html += "\nRetry buffer: ";
  int retryCount = 0;
  for (int i = 0; i < RETRY_BUFFER_SIZE; i++) {
    if (retryBuffer[i].valid) retryCount++;
  }
  html += String(retryCount);
  html += "</pre>";
  return html;
}

String floatOtaPageHtml() {
  String html;
  html.reserve(2200);
  html += "<!doctype html><html><head><meta name='viewport' content='width=device-width,initial-scale=1'>";
  html += "<title>SGNode Float OTA</title><style>body{font-family:sans-serif;margin:24px;max-width:720px}";
  html += "button,input{font-size:16px;padding:10px;margin:6px 0}pre{background:#f3f4f6;padding:12px;overflow:auto}";
  html += ".hdr{display:flex;align-items:center;gap:14px;margin-bottom:16px}.logo{width:96px;height:auto}</style></head><body>";
  html += "<div class='hdr'><img class='logo' src='/logo.png' alt='SGNode'><h2>Float OTA</h2></div>";
  html += "<form method='POST' action='/update' enctype='multipart/form-data'>";
  html += "<input type='file' name='update'><br><button type='submit'>Upload firmware</button></form>";
  html += "<p><a href='/diag'>Refresh diagnostics</a> | <a href='/reboot'>Reboot normal mode</a></p>";
  html += floatOtaDiagHtml();
  html += "</body></html>";
  return html;
}

void sendFloatOtaActiveStatus() {
  initESPNow();
  sg_float_ota_status_t status = {};
  status.packet_type = SG_FLOAT_OTA_STATUS_TYPE;
  status.version = SG_PROTOCOL_VERSION;
  status.sequence_id = rtcSequenceCounter++;
  status.uptime_s = millis() / 1000UL;
  strncpy(status.ssid, floatOtaSsid, sizeof(status.ssid) - 1);
  strncpy(status.ip, "192.168.4.1", sizeof(status.ip) - 1);
  status.timeout_s = OTA_TIMEOUT_MS / 1000UL;
  status.crc = sg_crc16((const uint8_t*)&status, sizeof(status) - sizeof(status.crc));
  esp_now_send(baseStationMac, (uint8_t*)&status, sizeof(status));
  delay(80);
  esp_now_deinit();
  WiFi.mode(WIFI_OFF);
}
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

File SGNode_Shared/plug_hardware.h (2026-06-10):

#pragma once

#include <Arduino.h>

namespace SGNodePlugHardware {

constexpr uint8_t PIN_LED_SECONDARY = 1;
constexpr uint8_t PIN_BUTTON = 3;
constexpr uint8_t PIN_AIR_SENSOR = 4;
constexpr uint8_t PIN_BEER_SENSOR = 5;
constexpr uint8_t PIN_LED_PRIMARY = 13;
constexpr uint8_t PIN_RELAY = 14;

constexpr uint8_t RELAY_ON_LEVEL = HIGH;
constexpr uint8_t RELAY_OFF_LEVEL = LOW;

constexpr uint32_t SERIAL_BAUD = 115200;

static_assert(PIN_AIR_SENSOR != PIN_BEER_SENSOR, "Each DS18B20 needs its own OneWire bus");
static_assert(PIN_RELAY != PIN_AIR_SENSOR, "Relay and air sensor pin collide");
static_assert(PIN_RELAY != PIN_BEER_SENSOR, "Relay and beer sensor pin collide");
static_assert(PIN_BUTTON != PIN_AIR_SENSOR, "Button and air sensor pin collide");
static_assert(PIN_BUTTON != PIN_BEER_SENSOR, "Button and beer sensor pin collide");
static_assert(RELAY_ON_LEVEL == HIGH, "Gosund SP1 relay must be active high");

inline void beginRelayOff() {
  digitalWrite(PIN_RELAY, RELAY_OFF_LEVEL);
  pinMode(PIN_RELAY, OUTPUT);
}

inline void setRelay(bool on) {
  digitalWrite(PIN_RELAY, on ? RELAY_ON_LEVEL : RELAY_OFF_LEVEL);
}

}  // namespace SGNodePlugHardware

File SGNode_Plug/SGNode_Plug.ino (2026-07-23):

#include <ESP8266WebServer.h>
#include <ESP8266WiFi.h>
#include <Updater.h>
#include <espnow.h>
#include <plug_hardware.h>
#include "../SGNode_Shared/sg_logo_png.h"

#include "src/air_controller.h"
#include "src/beer_pi_controller.h"
#include "src/plug_sensors.h"
#include "src/plug_selfcheck.h"
#include "src/plug_transport.h"
#include "src/plug_types.h"
#include "src/relay_history.h"

using namespace SGNodePlugHardware;

constexpr uint32_t SENSOR_INTERVAL_MS = 10000;
constexpr uint32_t DUTY_SAMPLE_INTERVAL_MS = 1000;
constexpr uint32_t PATTERN_INTERVAL_MS = 60000;
constexpr uint32_t STATUS_INTERVAL_MS = 60000;
constexpr uint32_t COMMAND_TIMEOUT_MS = 5UL * 60000UL;
constexpr uint32_t WARMING_TARGET_WINDOW_MS = 24UL * 3600000UL;
constexpr uint32_t OTA_BUTTON_HOLD_MS = 5000;
constexpr uint32_t OTA_WINDOW_MS = 180UL * 1000UL;
constexpr uint32_t OTA_BLINK_INTERVAL_MS = 300;
constexpr uint32_t BUTTON_DEBOUNCE_MS = 50;

PlugSensors sensors(PIN_AIR_SENSOR, PIN_BEER_SENSOR);
AirController airController;
BeerPiController beerPiController;
RelayDutyWindow relayDuty;
CompressorPattern compressorPattern;
PlugTransport transport;
SensorSnapshot latestSensors;
PlugControlMode controlMode = PlugControlMode::OFF;
uint16_t faults = PLUG_FAULT_NONE;
uint32_t lastSensorMs = 0;
uint32_t lastDutySampleMs = 0;
uint32_t lastPatternMs = 0;
uint32_t lastStatusMs = 0;
float airTargetC = NAN;
float beerTargetC = NAN;
float rampKPerHour = 0.2f;
float batchLiters = 20.0f;
float controllerKp = BeerPiController::DEFAULT_KP;
float controllerTnHours = 0.75f;
float controllerDBrakeHours = BeerPiController::DEFAULT_D_BRAKE_HOURS;
BeerPiSettings beerPiSettings;
AirControllerConfig airControllerConfig;
float beerUndershootLockoutC = 0.1f;
float fastWarmingRateKPerHour = 1.0f;
float targetStepC = 0.25f;
bool actualRelayOn = false;
uint16_t lastPrintedCommandSeq = 0;
float previousBeerTargetC = NAN;
bool warmingTargetActive = false;
uint32_t warmingTargetStartedMs = 0;
ESP8266WebServer otaServer(80);
bool otaModeActive = false;
bool otaUploadInProgress = false;
bool otaUploadOk = false;
uint32_t otaStartedMs = 0;
uint32_t otaLastClientMs = 0;
uint32_t otaRebootAtMs = 0;
uint32_t otaLastBlinkMs = 0;
bool otaBlinkPhase = false;
char otaSsid[32] = "";
bool buttonLastReading = false;
bool buttonStablePressed = false;
bool buttonLongPressFired = false;
uint32_t buttonLastChangeMs = 0;
uint32_t buttonPressStartedMs = 0;

void setActualRelay(bool on);
void printCommandIfChanged();
void updateOtaButton(uint32_t nowMs);
void startOtaMode(uint32_t nowMs);
void handleOtaMode(uint32_t nowMs);
void handleOtaRoot();
void handleOtaDiag();
void handleOtaLogo();
void handleOtaReboot();
void handleOtaUpdateDone();
void handleOtaUpload();
String otaDiagnosticText();

float clampPlugValue(float value, float minimum, float maximum) {
  if (value < minimum) return minimum;
  if (value > maximum) return maximum;
  return value;
}

void updateFaults(const SensorSnapshot& sample) {
  faults = PLUG_FAULT_NONE;
  if (!sample.airValid) {
    faults |= PLUG_FAULT_AIR_SENSOR;
  }
  if (!sample.beerValid) {
    faults |= PLUG_FAULT_BEER_SENSOR;
  }
  if (transport.hasCommand() && millis() - transport.lastCommandMs() > COMMAND_TIMEOUT_MS) {
    faults |= PLUG_FAULT_COMMAND_TIMEOUT;
  }
}

uint16_t statusFaultsForCurrentMode() {
  uint16_t statusFaults = faults;
  if (controlMode == PlugControlMode::AIR_ONLY_HOLD &&
      latestSensors.airValid &&
      !latestSensors.beerValid) {
    statusFaults &= ~PLUG_FAULT_BEER_SENSOR;
  }
  return statusFaults;
}

void applyCommandState(uint32_t nowMs) {
  if (!transport.hasCommand()) {
    controlMode = PlugControlMode::OFF;
    setActualRelay(false);
    return;
  }

  const sg_plug_command_t command = transport.command();
  if (isfinite(command.beer_target_c) && isfinite(previousBeerTargetC) &&
      fabsf(command.beer_target_c - previousBeerTargetC) > command.target_step_c) {
    warmingTargetActive = command.beer_target_c > previousBeerTargetC;
    warmingTargetStartedMs = warmingTargetActive ? nowMs : 0;
  }
  if (isfinite(command.beer_target_c)) {
    previousBeerTargetC = command.beer_target_c;
  }
  beerTargetC = command.beer_target_c;
  rampKPerHour = command.ramp_k_per_h;
  batchLiters = command.batch_liters;
  controllerKp = command.controller_kp;
  controllerTnHours = command.controller_tn_h;
  controllerDBrakeHours = command.controller_d_brake_h;
  beerPiSettings.kp = command.controller_kp;
  beerPiSettings.integralTnHours = command.controller_tn_h;
  beerPiSettings.dBrakeHours = command.controller_d_brake_h;
  beerPiSettings.coldIntegralBandC = command.cold_integral_band_c;
  beerPiSettings.warmIntegralBandC = command.warm_integral_band_c;
  beerPiSettings.maxPositiveIntegralC = command.max_positive_integral_c;
  beerPiSettings.maxNegativeIntegralC = command.max_negative_integral_c;
  beerPiSettings.integralLeakPerHour = command.integral_leak_per_hour;
  beerPiSettings.errorCrossingKeepFactor = command.error_crossing_keep_factor;
  beerPiSettings.maxDOffsetC = command.max_d_offset_c;
  beerPiSettings.warmingDFactor = command.warming_d_factor;
  beerPiSettings.strongUndershootC = command.strong_undershoot_c;
  beerPiSettings.strongUndershootAirOffsetC = command.strong_undershoot_air_offset_c;
  beerPiSettings.minAirTargetC = command.min_air_target_c;
  beerPiSettings.maxAirTargetC = command.max_air_target_c;
  beerPiSettings.targetStepC = command.target_step_c;
  beerPiSettings.rampControllerKpHours = command.ramp_controller_kp_h;
  beerPiSettings.rampControllerTnHours = command.ramp_controller_tn_h;
  beerPiSettings.maxRampTrimC = command.max_ramp_trim_c;
  beerPiSettings.rampFadeDistanceC = command.ramp_fade_distance_c;
  beerPiSettings.rateFilterSamples = command.rate_filter_samples;
  airControllerConfig.turnOffAboveTargetC = command.air_turn_off_above_target_c;
  airControllerConfig.turnOnAboveTargetC = command.air_turn_on_above_target_c;
  airControllerConfig.minimumOnMs = (uint32_t)command.air_minimum_on_s * 1000UL;
  airControllerConfig.minimumOffMs = (uint32_t)command.air_minimum_off_s * 1000UL;
  airController.setConfig(airControllerConfig);
  beerUndershootLockoutC = command.beer_undershoot_lockout_c;
  fastWarmingRateKPerHour = command.fast_warming_rate_k_per_h;
  targetStepC = command.target_step_c;

  if (nowMs - transport.lastCommandMs() > COMMAND_TIMEOUT_MS) {
    controlMode = PlugControlMode::OFF;
    faults |= PLUG_FAULT_COMMAND_TIMEOUT;
    setActualRelay(false);
    return;
  }

  if ((command.flags & SG_PLUG_COMMAND_ENABLE) == 0) {
    controlMode = PlugControlMode::OFF;
    setActualRelay(false);
    return;
  }

  if (controlMode == PlugControlMode::OFF || controlMode == PlugControlMode::FAULT) {
    controlMode = PlugControlMode::AUTOMATIC;
  }
}
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

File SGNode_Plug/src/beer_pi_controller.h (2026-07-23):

#pragma once

#include <Arduino.h>

struct BeerPiSettings {
  float kp = 0.45f;
  float integralTnHours = 0.75f;
  float dBrakeHours = 0.8f;
  float coldIntegralBandC = 1.0f;
  float warmIntegralBandC = 0.5f;
  float maxPositiveIntegralC = 2.0f;
  float maxNegativeIntegralC = -0.6f;
  float integralLeakPerHour = 1.0f;
  float errorCrossingKeepFactor = 0.25f;
  float maxDOffsetC = 0.9f;
  float warmingDFactor = 0.25f;
  float strongUndershootC = 1.0f;
  float strongUndershootAirOffsetC = 1.8f;
  float minAirTargetC = 1.0f;
  float maxAirTargetC = 30.0f;
  float targetStepC = 0.25f;
  float rampControllerKpHours = 0.8f;
  float rampControllerTnHours = 3.0f;
  float maxRampTrimC = 1.0f;
  float rampFadeDistanceC = 1.0f;
  float rateFilterSamples = 5.0f;
};

class BeerPiController {
 public:
  static constexpr uint8_t AVERAGE_SAMPLES = 60;
  static constexpr uint8_t CONTROL_AVERAGE_SAMPLES = 6;
  static constexpr float DEFAULT_KP = 0.45f;
  static constexpr float DEFAULT_D_BRAKE_HOURS = 0.8f;
  static constexpr float DEADBAND_C = 0.1f;

  void addBeerSample(float beerC, bool valid);
  float update(float beerTargetC, float rampKPerHour, float batchLiters,
               const BeerPiSettings& settings, uint32_t nowMs);
  void reset();

  float beerAverageC() const;
  float beerControlC() const;
  float beerRateCPerHour() const;
  float beerRateRawCPerHour() const;
  float airTargetC() const;
  float offsetC() const;
  float pOffsetC() const;
  float iOffsetC() const;
  float dOffsetC() const;
  float rampTrimC() const;
  float rampITrimC() const;
  float rampRateErrorKPerHour() const;
  float tnHours() const;
  float kp() const;
  float dBrakeHours() const;
  static float calculateTnHours(float batchLiters);

 private:
  float samples_[AVERAGE_SAMPLES] = {};
  uint32_t sampleTimesMs_[AVERAGE_SAMPLES] = {};
  uint8_t next_ = 0;
  uint8_t count_ = 0;
  float sum_ = 0.0f;
  float integral_ = 0.0f;
  float airTargetC_ = NAN;
  float offsetC_ = 0.0f;
  float pOffsetC_ = 0.0f;
  float iOffsetC_ = 0.0f;
  float dOffsetC_ = 0.0f;
  float rampIntegralC_ = 0.0f;
  float rampTrimC_ = 0.0f;
  float rampRateErrorKPerHour_ = 0.0f;
  float beerRateRawCPerHour_ = 0.0f;
  float tnHours_ = 0.75f;
  float kp_ = DEFAULT_KP;
  float dBrakeHours_ = DEFAULT_D_BRAKE_HOURS;
  float beerRateCPerHour_ = 0.0f;
  bool beerRateFilterPrimed_ = false;
  float lastBeerTargetC_ = NAN;
  float lastErrorC_ = NAN;
  uint32_t lastUpdateMs_ = 0;

  float calculateBeerRateCPerHour() const;
};

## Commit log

2026-04-24 Release v0.1.0-alpha - SGNode fermentation monitoring system
    - Rebranded to SGNode
    - Fixed payload_t struct mismatch between float and base station
    - Added CRC16 data integrity verification
    - Added battery voltage monitoring and percentage display
    - Implemented OG automatic capture with stability detection
    - Added ABV real-time calculation
    - Reorganized file structure for Arduino IDE compatibility
    - Added .gitignore and CHANGELOG.md
    - Updated documentation
    [SGNode_Float.ino, polynomial_calibration.h]
2026-04-27 Update documentation and add hardware specifications
    - Updated README.md file structure to include logo.h and documentation files
    - Added hardware.md with detailed BOM and specifications
    - Added CHANGELOG.md for tracking project changes
    - Added logo.h boot logo image to SGNode_Base
    - Updated calibration and firmware files
2026-04-28 v0.2.0-beta: Critical fixes and major improvements
    ✅ Critical Fixes:
    - Fixed missing computeSensorData() function completing state machine
    - Fixed ESP-NOW communication with unicast and peer management
    - Fixed header multiple definition errors with extern declarations
    - Fixed base station MAC address display (was showing zeros)
    - Fixed calibration header design preventing project expansion
    - Fixed function prototype mismatches and missing implementations
    🔧 Major Enhancements:
    - Added comprehensive debug system with conditional compilation
    - Added automatic ESP-NOW peer registration and MAC tracking
    - Added complete state machine implementation (INIT/MEASURE/COMPUTE/SEND/SLEEP)
    - Added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
    [SGNode_Float.ino, polynomial_calibration.h]
2026-05-06 Release v0.3.0-alpha - Design Freeze with Complete System Stabilization
    Critical Fixes:
    - Fixed polynomial calibration bug (matrix back substitution and coefficient mapping)
    - Fixed base station calibration communication (rate limiting reset)
    - Fixed SD card file corruption (filename validation)
    - Fixed historical data loading on reboot
    - Fixed battery voltage calibration (1.048 factor for 13% error correction)
    Major Features:
    - Complete 3rd degree polynomial calibration with least squares
    - Historical data persistence across reboots
    - Comprehensive system safeguards and error handling
    - File corruption prevention with CSV validation
    - Accurate battery voltage measurement
    Documentation:
    -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
    [SGNode_Float.ino, polynomial_calibration.h, ui_components.cpp]
2026-05-17 docs: add sensor offset calibration to README
    - Added Step 1/5 for sensor offset calibration in calibration procedure
    - Documented IMU offset calibration for zero-angle when flat
    - Updated step numbering for SG calibration (now Steps 2-5)
    - Enhanced calibration notes to explain both calibration types
2026-05-17 feat: add sensor offset calibration system and UI improvements
    - Added sensor offset calibration (Step 1/5) to float and base station
    - Implemented CALIBRATE_OFFSET command (command 5) in protocol
    - Added EEPROM storage for sensor offsets (X, Y, Z axes)
    - Updated calibration wizard UI with offset calibration step
    - Added offset calibration buttons and state management
    - Improved calibration workflow with 5-step process
    - Added Logo2_Optimized_Data_Cleaned.h for optimized logo display
    - Updated UI tokens and components for calibration improvements
    - Removed CHANGELOG.md (replaced by RELEASE_NOTES)
    - Updated hardware documentation
    - Updated improvement schedule
    [SGNode_Float.ino, polynomial_calibration.h, ui_components.cpp]
2026-06-04 Stabilize fermentation guidance and reorganize base firmware
    [Base.3mf, Float.3mf]
2026-06-16 Stabilize SGNode Plug controller tuning
    [SGNode_Plug.ino, beer_pi_controller.h]
2026-07-23 Codex Updates: Temperaturprofile, Post-Package Graph und BatchAction Korrektur
